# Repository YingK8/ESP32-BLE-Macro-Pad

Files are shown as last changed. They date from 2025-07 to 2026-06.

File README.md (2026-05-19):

# ESP32 BLE HID Macropad

A compact, programmable macropad with Bluetooth connectivity, featuring 6 mechanical keys and a rotary encoder for media control.





## Features

- 6-key mechanical switch matrix
- Rotary encoder for volume/scroll control
- Bluetooth HID (no drivers required)
- Supports both keyboard and media controls
- Customizable key mappings

## Hardware

| Component | Quantity |
|---|---|
| ESP32 Dev Board | 1 |
| Mechanical Keyswitches | 6 |
| Rotary Encoder | 1 |
| 1N4148 Diodes | 6 |

## Pinout

| Function | ESP32 Pin |
|---|---|
| Row 1 | GPIO 5 |
| Row 2 | GPIO 6 |
| Col 1 | GPIO 4 |
| Col 2 | GPIO 7 |
| Col 3 | GPIO 8 |
| Encoder A | GPIO 9 |
| Encoder B | GPIO 10 |

## Installation

1. Wire components according to pinout table
2. Install Arduino IDE with ESP32 support
3. Install required libraries:
   - ESP32 BLE Arduino
   - RotaryEncoder
4. Upload firmware to ESP32

## Usage

1. Power on the macropad
2. Pair with "ESP32 Macropad" via Bluetooth
3. Default layout:
   - Top row: Media controls
   - Bottom row: Programmable macros
   - Encoder: Volume control

## Customization

Edit the keymap in the source code:

```cpp
const uint8_t keys[ROWS][COLS] = {
  {MEDIA_PLAY, MEDIA_VOL_UP, MEDIA_VOL_DOWN},
  {KEY_F13, KEY_F14, KEY_F15}
};

## Pomodoro UI + Task Sync (macro-pad/)

- Display: ST7789 240x280 SPI. Set pins in `macro-pad/include/Config.h`.
- Controls: top-left key toggles pause/resume; encoder rotation moves selection; top-right key (encoder click in matrix) checks/unchecks a task.
- Task payload: newline-delimited titles terminated by `--END--`.

CLI helper (requires `pip install bleak`):

```bash
python3 macro-pad/tools/push_tasks.py "Write report" "Review PRs"
```

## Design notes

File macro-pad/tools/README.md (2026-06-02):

# Task Push Tools

Two Python scripts for sending a task list to the MacroPad over BLE. Both do the same job; `send_tasks.py` is simpler for quick CLI use, `push_tasks.py` has more flags (`--address`, `--timeout`).

## Requirements

```
pip install bleak
```

## Usage

```bash
# Inline tasks
python send_tasks.py "grasp map" "orca handoff" "teleop"

# From a file (one task per line)
python send_tasks.py --file tasks.txt

# push_tasks.py with optional flags
python push_tasks.py --name "ESP32 MacroPad" --timeout 8.0 "task one" "task two"
python push_tasks.py --address AA:BB:CC:DD:EE:FF --file tasks.txt
```

Tasks are automatically uppercased before sending — the display font only contains capital letters.

---

## How it works: end-to-end

### 1. BLE GATT — the transport layer

BLE (Bluetooth Low Energy) uses a client/server model called **GATT** (Generic Attribute Profile).

- The **ESP32 is the server**: it hosts a *Service* (a logical grouping) that contains a *Characteristic* (a named data slot). Think of a characteristic like a file you can read or write over the air.
- The **laptop is the client**: it connects, discovers the service, and writes bytes to the characteristic.

Services and characteristics are identified by **UUIDs** (128-bit IDs). Both tools and the firmware share the same pair:

```
Service UUID:        c3a7b7a0-3c1b-4d46-9f5c-9f0d9d1a9d01
Characteristic UUID: c3a7b7a0-3c1b-4d46-9f5c-9f0d9d1a9d02
```

### 2. MTU and chunking

BLE ATT (Attribute Protocol) has a default **MTU of 23 bytes**, leaving only **20 bytes of usable payload** per write (3 bytes are consumed by the ATT header). Without explicit MTU negotiation, any write larger than 20 bytes will be silently truncated or rejected.

The tools split the payload into 20-byte chunks and write them one at a time:

```python
for i in range(0, len(data), CHUNK_SIZE):
    await client.write_gatt_char(CHAR_UUID, data[i:i + CHUNK_SIZE], response=False)
```

`response=False` uses **Write Without Response** (BLE opcode 0x52), which is faster than a confirmed write but provides no acknowledgement. It is appropriate here because the terminator-detection scheme makes retries unnecessary.

### 3. The terminator protocol

Because the payload arrives as many small chunks, the ESP32 can't know when the transfer is complete from any single write. The protocol uses a sentinel string `--END--` to mark the end:

```
GRASP MAP\nORCA HANDOFF\nTELEOP\n--END--
│                                │
└─ newline-separated task names  └─ sentinel
```

The firmware accumulates chunks in a fixed buffer and scans for `--END--` after each write:

```cpp
// TaskSync.cpp — onWrite()
const char* term = strstr(_buf, "--END--");
if (term) {
    enqueue(_buf, term - _buf);  // copy everything before "--END--"
    _buf[0] = '\0';              // reset for next transfer
}
```

Everything before the sentinel is the complete payload; the sentinel itself is discarded.

### 4. Thread-safety with a spinlock

BLE callbacks run in a FreeRTOS task managed by the ESP32 BLE stack — a different task from the Arduino `loop()`. Sharing memory between them without protection causes **race conditions** (one task reads while the other writes, getting garbled data).

TaskSync uses a **spinlock** (`portMUX_TYPE`) to make the handoff atomic:

```cpp
// Writer side (BLE callback task):
portENTER_CRITICAL(&taskMux);
memcpy(pendingPayload, data, n);
payloadReady = true;
portEXIT_CRITICAL(&taskMux);

// Reader side (loop() task):
portENTER_CRITICAL(&taskMux);
strncpy(out, pendingPayload, maxLen - 1);
payloadReady = false;
portEXIT_CRITICAL(&taskMux);
```

`portENTER_CRITICAL` on a single-core ESP32-C3 disables interrupts for the critical section. `payloadReady` is marked `volatile` so the compiler doesn't cache its value in a register across the critical section boundary.

### 5. Parsing the payload

Once `loop()` picks up the payload via `getNextTaskPayload()`, `applyTasks()` parses it line by line:

```cpp
const char* nl = strchr(p, '\n');
size_t len = nl ? (size_t)(nl - p) : strlen(p);  // handles last line with no \n
```

Each task is uppercased (ASCII arithmetic: `*q -= 32` maps 'a'→'A'), stored in `tasks[][]`, and the display is flagged dirty for the next `loop()` iteration.

### 6. Display update

`buildScreen()` in `ui.cpp` rebuilds the entire screen as one flat string and hands it to LVGL's label renderer. Tasks appear as 12-character rows:

```
1 GRASP MAP  
2 ORCA HANDOF   ← truncated at 12 chars silently
3 TELEOP     <  ← selected row gets '<' cursor
```

---

## Full data flow

```
Python                ESP32 BLE stack          Arduino loop()        LVGL
──────                ───────────────          ──────────────        ────
tasks.upper()
→ payload string
→ split into 20B chunks
→ write_gatt_char() ×N
                      onWrite() ×N
                      accumulate in _buf
                      strstr("--END--") found
                      enqueue(payload)         getNextTaskPayload()
                                               applyTasks()
                                               tasksDirty = true
                                               updateTaskQueue()     buildScreen()
                                                                     lv_label_set_text()
                                                                     → pixels on display
```

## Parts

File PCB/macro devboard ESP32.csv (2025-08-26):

Reference | Qty | Value | DNP | Exclude from BOM | Exclude from Board | Footprint | Datasheet
C1,C6,C7 | 3 | 100nF |  |  |  | Capacitor_SMD:C_0603_1608Metric_Pad1.08x0.95mm_HandSolder | ~
C3,C4,C5,C8,C9 | 5 | 2.2uF |  |  |  | Capacitor_SMD:C_0603_1608Metric_Pad1.08x0.95mm_HandSolder | ~
D2,D3,D4,D5,D6,D7,D11 | 7 | 1N4148WT |  |  |  | Diode_SMD:D_SOD-323F | https://www.diodes.com/assets/Datasheets/ds30396.pdf
D8,D9,D10,D12 | 4 | LED |  |  |  | LED_SMD:LED_0805_2012Metric_Pad1.15x1.40mm_HandSolder | https://mm.digikey.com/Volume0/opasdata/d220001/medias/docus/1134/LTST-C171GKT.pdf,~
H1,H2 | 2 | MountingHole |  | Excluded from BOM |  | MountingHole:MountingHole_2.7mm_M2.5 | ~
J1 | 1 | 12402012E212A |  |  |  | 12402012E212A:AMPHENOL_12402012E212A
J2 | 1 | Conn_01x02_Pin |  |  |  | Connector_JST:JST_PH_B2B-PH-K_1x02_P2.00mm_Vertical | ~
J3 | 1 | Conn_02x04_Odd_Even |  |  |  | Connector_PinSocket_2.54mm:PinSocket_2x04_P2.54mm_Vertical | ~
JP10,JP11 | 2 | SolderJumper_2_Open |  | Excluded from BOM |  | Jumper:SolderJumper-2_P1.3mm_Open_RoundedPad1.0x1.5mm | ~
Q1 | 1 | BSS84LT1G |  |  |  | Package_TO_SOT_SMD:TSOT-23_HandSoldering | https://ngspice.sourceforge.io/docs/ngspice-html-manual/manual.xhtml#cha_MOSFETs
R1,R2 | 2 | 5.1k |  |  |  | Resistor_SMD:R_0603_1608Metric_Pad0.98x0.95mm_HandSolder | ~
R4,R5 | 2 | 22 |  |  |  | Resistor_SMD:R_0603_1608Metric_Pad0.98x0.95mm_HandSolder | ~
R6,R7,R11 | 3 | 100 |  |  |  | Resistor_SMD:R_0603_1608Metric_Pad0.98x0.95mm_HandSolder | ~
R10 | 1 | 100k |  |  |  | Resistor_SMD:R_0603_1608Metric_Pad0.98x0.95mm_HandSolder | ~
R12 | 1 | 10k |  |  |  | Resistor_SMD:R_0603_1608Metric_Pad0.98x0.95mm_HandSolder | ~
R13 | 1 | 2.2k |  |  |  | Resistor_SMD:R_0603_1608Metric_Pad0.98x0.95mm_HandSolder | ~
R14 | 1 | 2.7k |  |  |  | Resistor_SMD:R_0603_1608Metric_Pad0.98x0.95mm_HandSolder | ~
S1 | 1 | PEC12R-4225F-S0024 |  |  |  | PEC12R_4225F_S0024:XDCR_PEC12R-4225F-S0024
SW1,SW6,SW7,SW8,SW9 | 5 | MX_SW_HS |  |  |  | keyswitches:Kailh_socket_MX | ~
SW3 | 1 | RST |  |  |  | Button_Switch_SMD:SW_Tactile_SPST_NO_Straight_CK_PTS636Sx25SMTRLFS | ~
U1 | 1 | ESP32-C3-WROOM-02 |  |  |  | RF_Module:ESP32-C3-WROOM-02 | https://www.espressif.com/sites/default/files/documentation/esp32-c3-wroom-02_datasheet_en.pdf
U2 | 1 | MCP73831T-2ACI_OT |  |  |  | MCP73831T_2ACI_OT:SOT95P280X145-5N
U3 | 1 | USBLC6-2SC6 |  |  |  | Package_TO_SOT_SMD:SOT-23-6_Handsoldering | https://www.st.com/resource/en/datasheet/usblc6-2.pdf
U4 | 1 | XC6210B332MR |  |  |  | Package_TO_SOT_SMD:SOT-23-5 | https://www.torexsemi.com/file/xc6210/XC6210.pdf

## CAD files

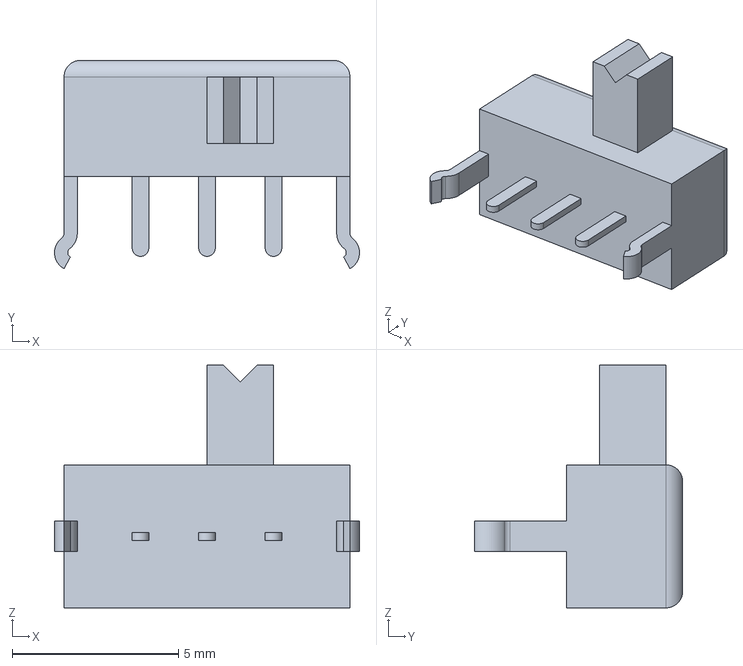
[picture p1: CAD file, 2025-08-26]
PCB/components/1825232_1/c-1825232-1-b-3d.stp
9.17 x 6.27 x 7.30 mm

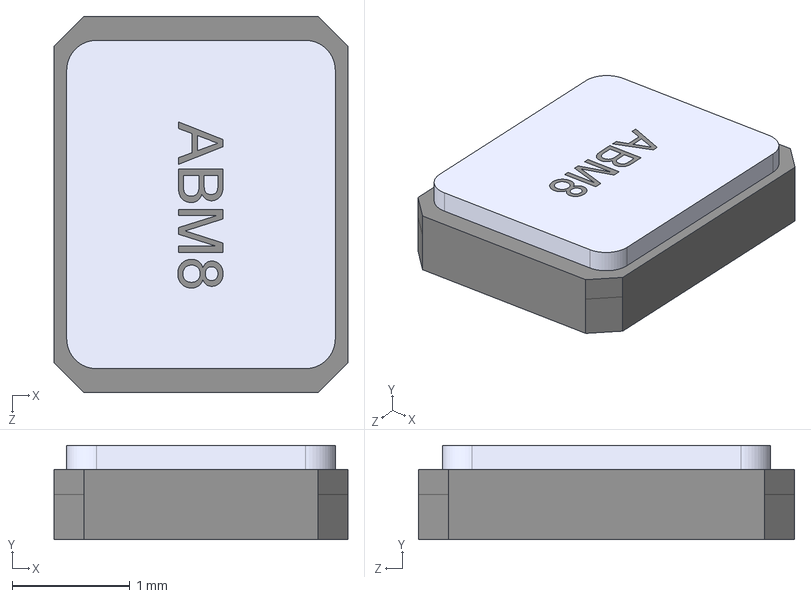
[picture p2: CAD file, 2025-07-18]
PCB/components/ABM8_16_000MHZ_D1X_T/ABM8-16.000MHz-D1X-T.step
2.50 x 0.8 x 3.20 mm

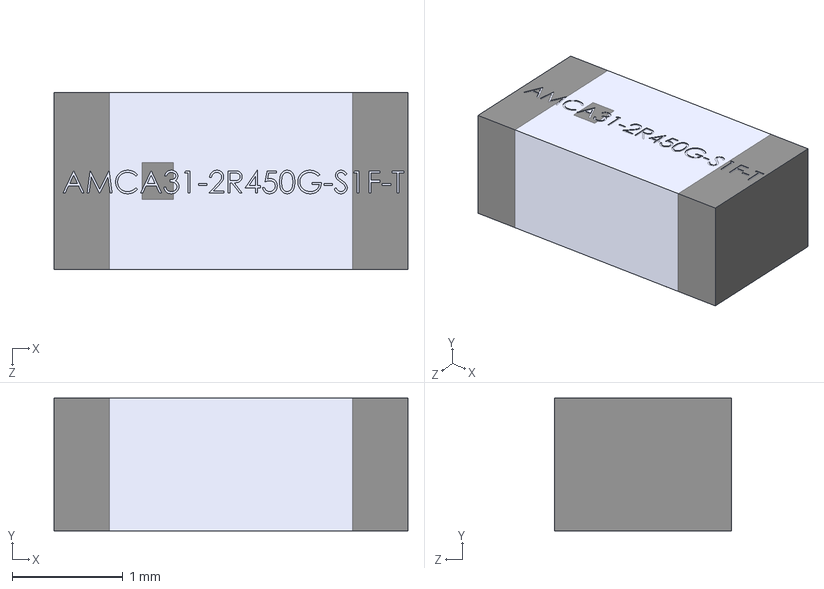
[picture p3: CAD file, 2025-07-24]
PCB/components/AMCA31_2R450G_S1F_T3/AMCA31-2R450G-S1F-T3.step
3.20 x 1.20 x 1.60 mm

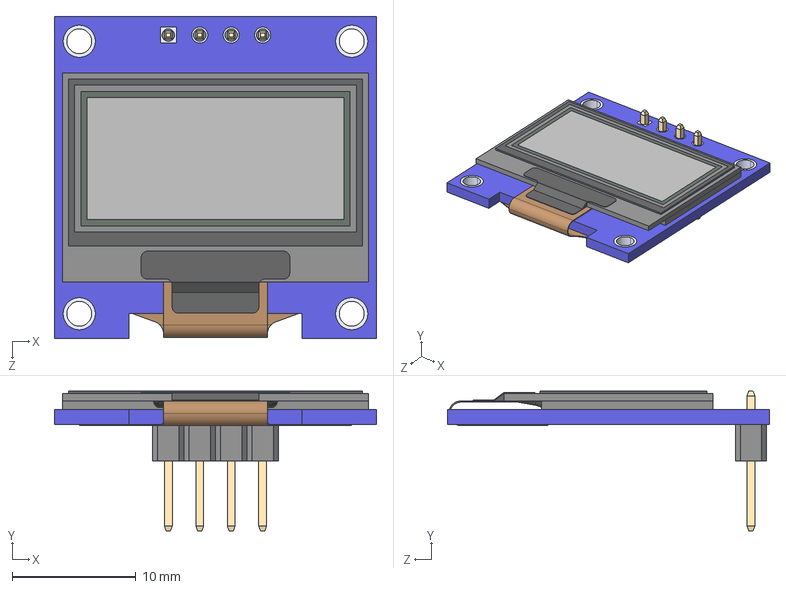
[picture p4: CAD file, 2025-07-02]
PCB/components/DM-OLED096-636/DM-OLED096-636.step
26.0 x 11.3 x 26.0 mm
DM-OLED096-636_Module
DM-OLED096-636_Panel

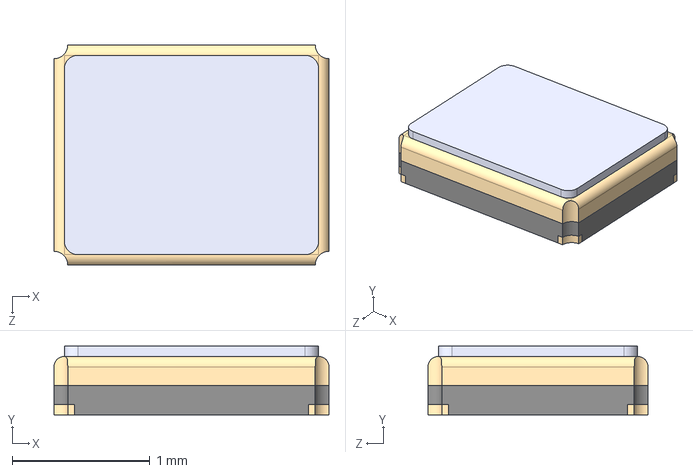
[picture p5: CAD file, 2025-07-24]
PCB/components/ECS_320_8_37B_CKY_TR/ECS-320-8-37B-CKY-TR.step
2.00 x 0.5 x 1.60 mm

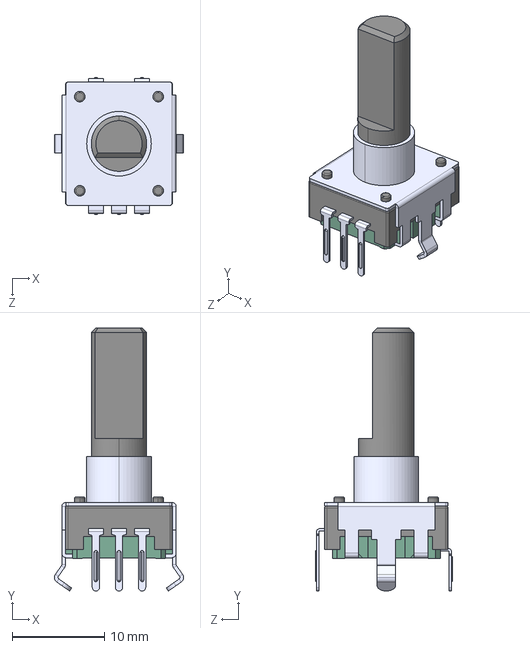
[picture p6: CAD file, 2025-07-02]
PCB/components/PEC12R_4225F_S0024/PEC12R-4225F-S0024.step
14.0 x 28.5 x 14.9 mm

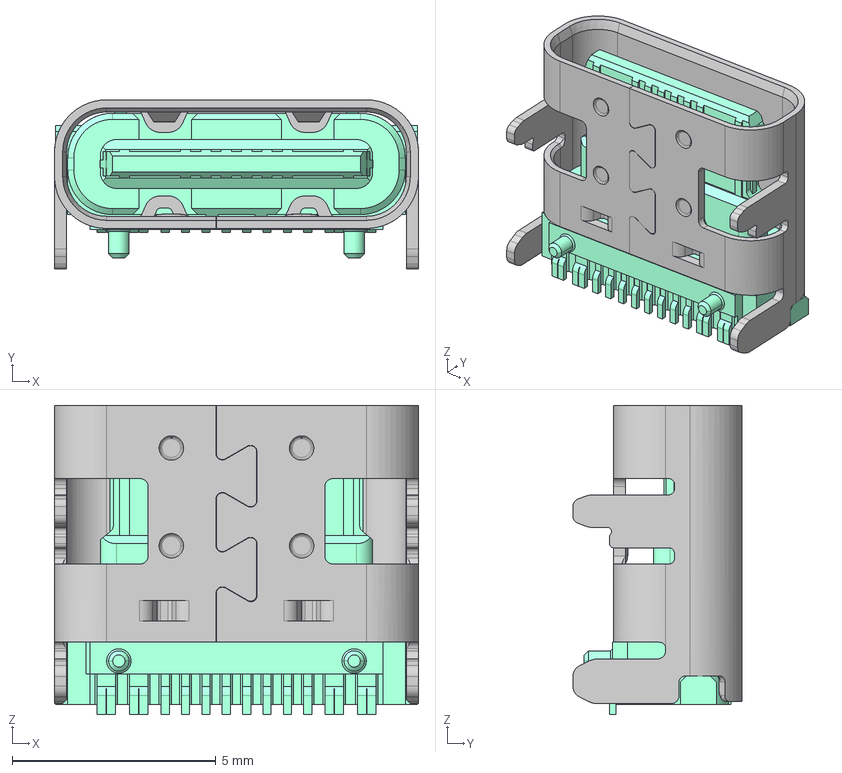
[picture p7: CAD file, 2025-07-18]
PCB/components/12402012E212A/12402012E212A.step
8.94 x 4.16 x 7.60 mm

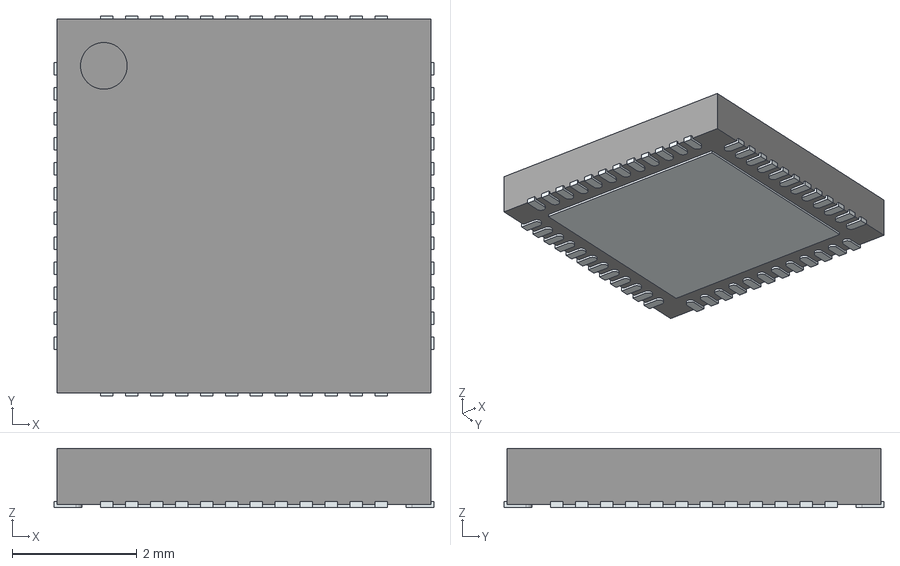
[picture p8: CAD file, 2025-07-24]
PCB/components/LIB_nRF52840-QFAA-F-R7/nRF52840-QFAA-F-R7/3D/nRF52840-QFAA-F-R7.stp
6.10 x 6.10 x 0.95 mm
ThermalPin
PinsArrayLR
PinsArrayTB

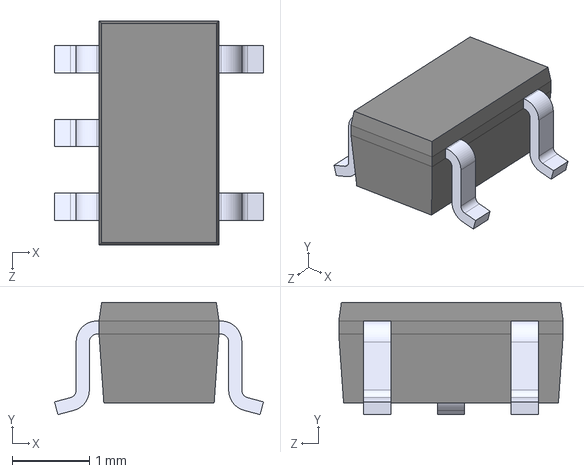
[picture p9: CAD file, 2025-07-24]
PCB/components/MCP73831T_2ACI_OT/MCP73831T-2ACI_OT.step
2.70 x 1.45 x 2.90 mm

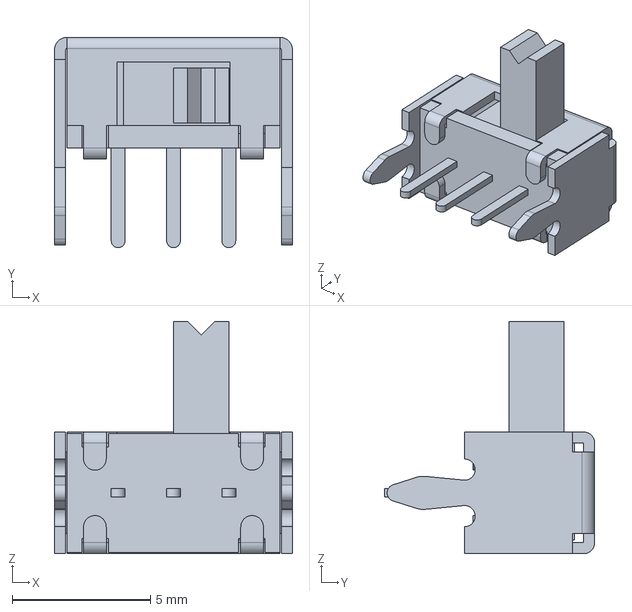
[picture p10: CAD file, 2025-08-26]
PCB/components/OS102011MA1QN1/OS102011MA1QN1.stp
8.60 x 7.60 x 8.40 mm

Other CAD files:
PCB/components/LIB_nRF52840-QFAA-F-R7/nRF52840-QFAA-F-R7/Allegro/qfn40p600x600x95-49n-d.psm
PCB/components/LIB_nRF52840-QFAA-F-R7/nRF52840-QFAA-F-R7/DEHDL/nrf52840_qfaa_f_r7/chips/chips.prt

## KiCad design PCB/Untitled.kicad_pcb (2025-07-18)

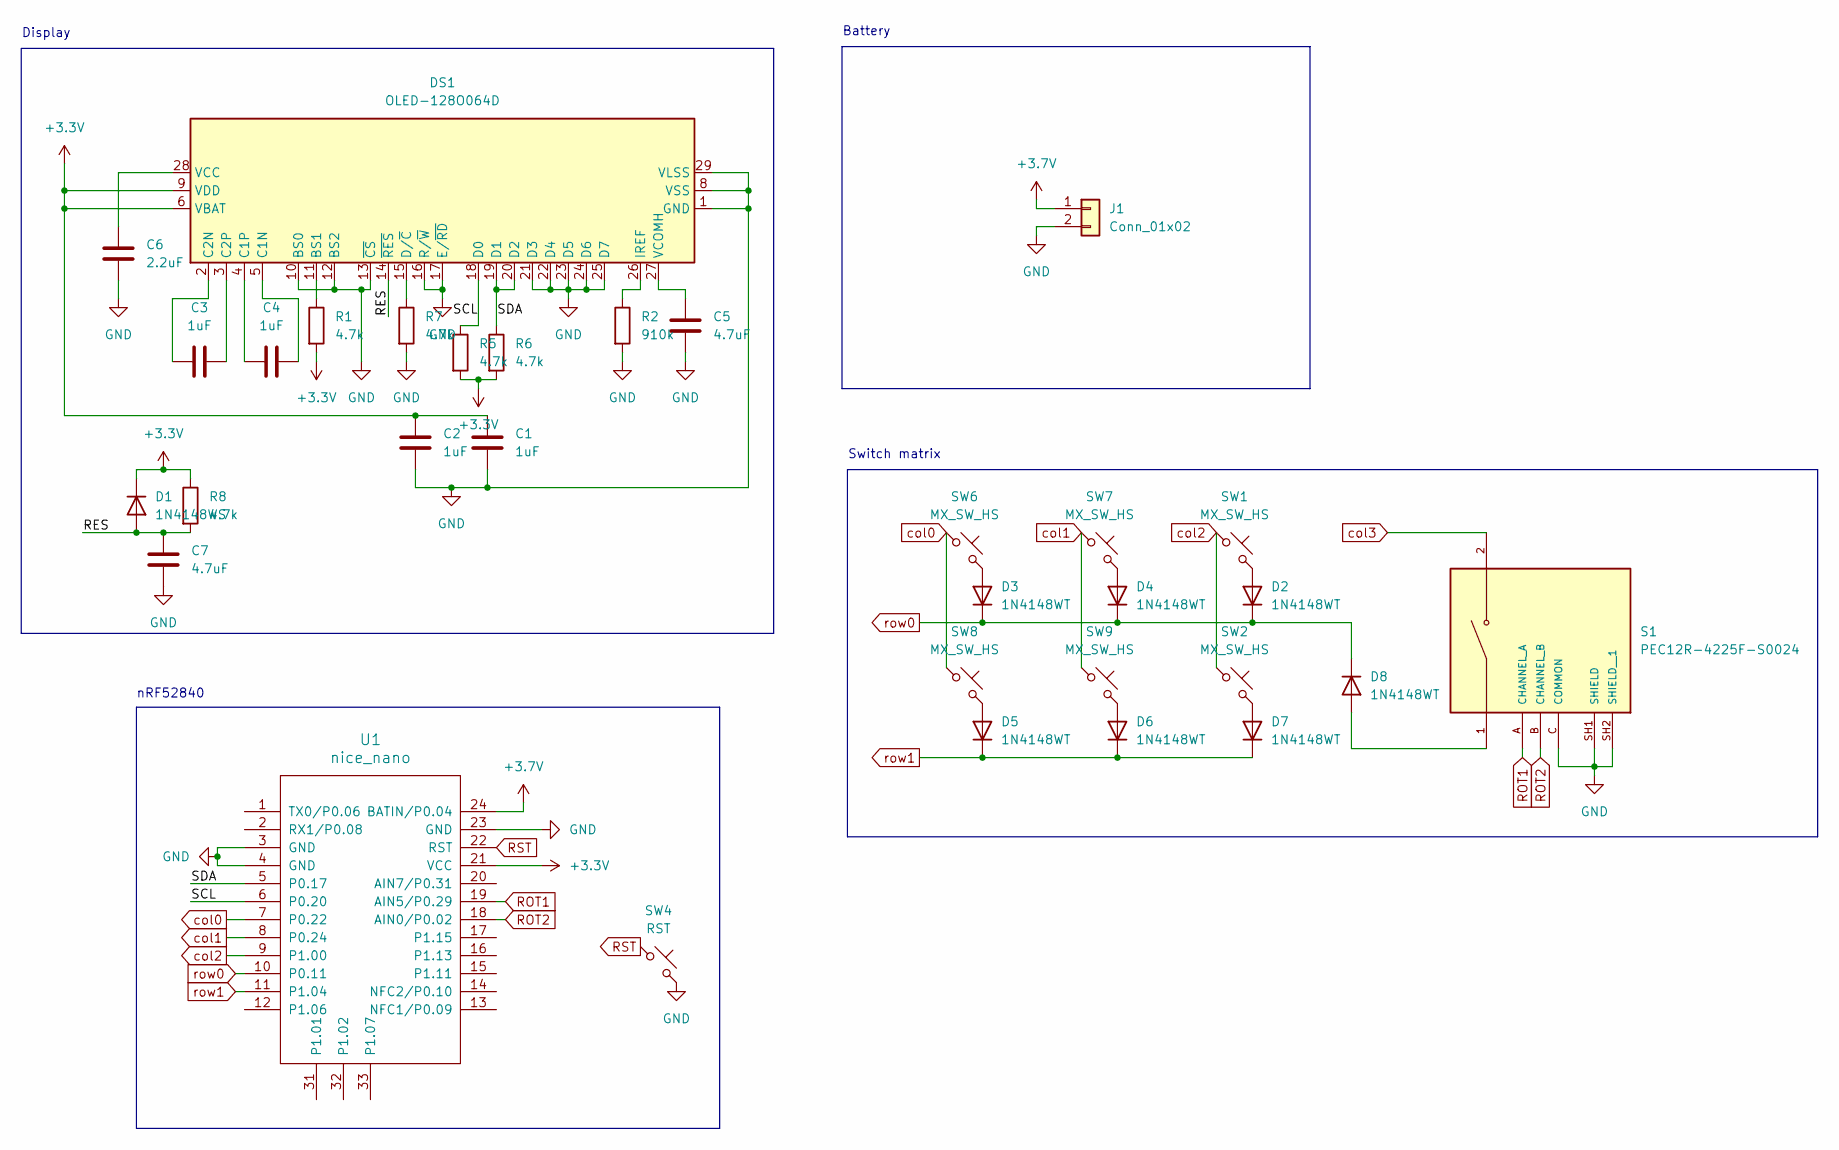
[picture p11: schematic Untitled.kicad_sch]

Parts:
C1, C2, C3, C4: 1uF; C_0805_2012Metric_Pad1.18x1.45mm_HandSolder
C5, C7: 4.7uF; C_0805_2012Metric_Pad1.18x1.45mm_HandSolder
C6: 2.2uF; C_0805_2012Metric_Pad1.18x1.45mm_HandSolder
D1: 1N4148WS; D_SOD-323F
D2, D3, D4, D5, D6, D7, D8: 1N4148WT; D_SOD-323F
DS1: OLED-128O064D
J1: Conn_01x02; JST_PH_S2B-PH-K_1x02_P2.00mm_Horizontal
R1, R5, R6, R7, R8: 4.7k; R_0805_2012Metric_Pad1.20x1.40mm_HandSolder
R2: 910k; R_0805_2012Metric_Pad1.20x1.40mm_HandSolder
S1: PEC12R-4225F-S0024; XDCR_PEC12R-4225F-S0024; PARTREV 07/21
SW1, SW2, SW6, SW7, SW8, SW9: MX_SW_HS; Kailh_socket_MX
SW4: RST; SW_Tactile_SPST_NO_Straight_CK_PTS636Sx25SMTRLFS
U1: nice_nano

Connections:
+3.3V: C1.2, C2.2, D1.1 (K), DS1.6 (VBAT), DS1.9 (VDD), R1.2, R5.2, R6.2, R8.1, U1.21 (VCC)
+3.7V: J1.1, U1.24 (BATIN/P0.04)
/RES: C7.2, D1.2 (A), DS1.14 (~RES), R8.2
/SCL: DS1.18 (D0), R5.1, U1.6 (P0.20)
/SDA: DS1.19 (D1), DS1.20 (D2), R6.1, U1.5 (P0.17)
GND: C1.1, C2.1, C5.1, C6.1, C7.1, DS1.1 (GND), DS1.8 (VSS), DS1.10 (BS0), DS1.12 (BS2), DS1.13 (~CS), DS1.16 (R/~W), DS1.17 (E/~RD), DS1.21 (D3), DS1.22 (D4), DS1.23 (D5), DS1.24 (D6), DS1.25 (D7), DS1.29 (VLSS), DS1.30 (GND), J1.2, R2.2, R7.2, S1.C (COMMON), S1.SH1 (SHIELD), S1.SH2 (SHIELD__1), SW4.2, U1.3 (GND), U1.4 (GND), U1.23 (GND)
unnamed: D2.2 (A), SW1.2
unnamed: D3.2 (A), SW6.2
unnamed: D4.2 (A), SW7.2
unnamed: D5.2 (A), SW8.2
unnamed: D6.2 (A), SW9.2
unnamed: D7.2 (A), SW2.2
unnamed: D8.2 (A), S1.1
unnamed: DS1.11 (BS1), R1.1
unnamed: C4.2, DS1.5 (C1N)
unnamed: C4.1, DS1.4 (C1P)
unnamed: C3.1, DS1.2 (C2N)
unnamed: C3.2, DS1.3 (C2P)
unnamed: DS1.15 (D/~C), R7.1
unnamed: DS1.26 (IREF), R2.1
unnamed: C6.2, DS1.28 (VCC)
unnamed: C5.2, DS1.27 (VCOMH)
ROT1: S1.A (CHANNEL_A), U1.19 (AIN5/P0.29)
ROT2: S1.B (CHANNEL_B), U1.18 (AIN0/P0.02)
RST: SW4.1, U1.22 (RST)
col0: SW6.1, SW8.1, U1.7 (P0.22)
col1: SW7.1, SW9.1, U1.8 (P0.24)
col2: SW1.1, SW2.1, U1.9 (P1.00)
col3: S1.2
row0: D2.1 (K), D3.1 (K), D4.1 (K), D8.1 (K), U1.10 (P0.11)
row1: D5.1 (K), D6.1 (K), D7.1 (K), U1.11 (P1.04)

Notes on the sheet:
Battery
Display
Switch matrix
nRF52840

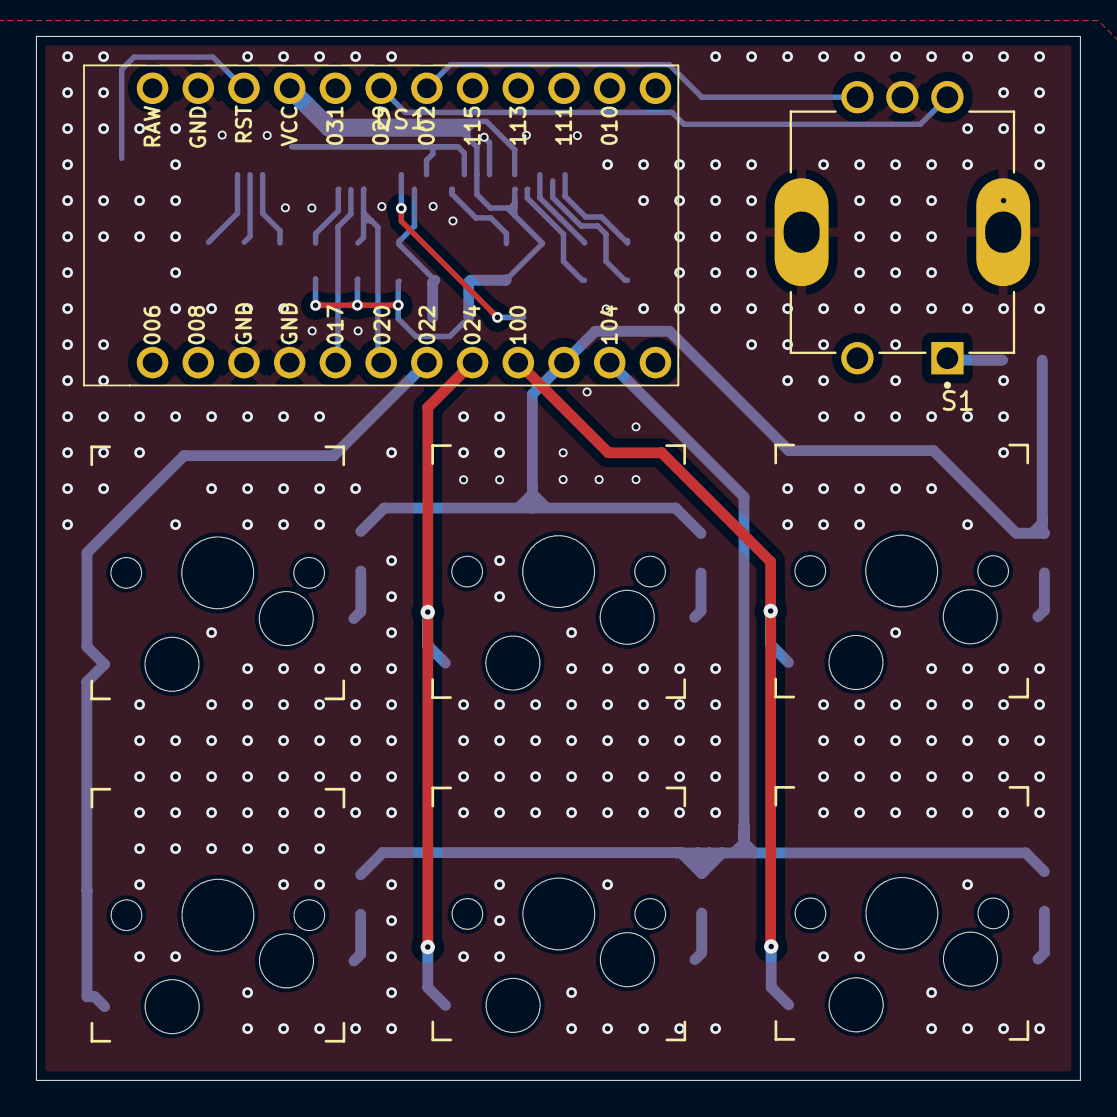
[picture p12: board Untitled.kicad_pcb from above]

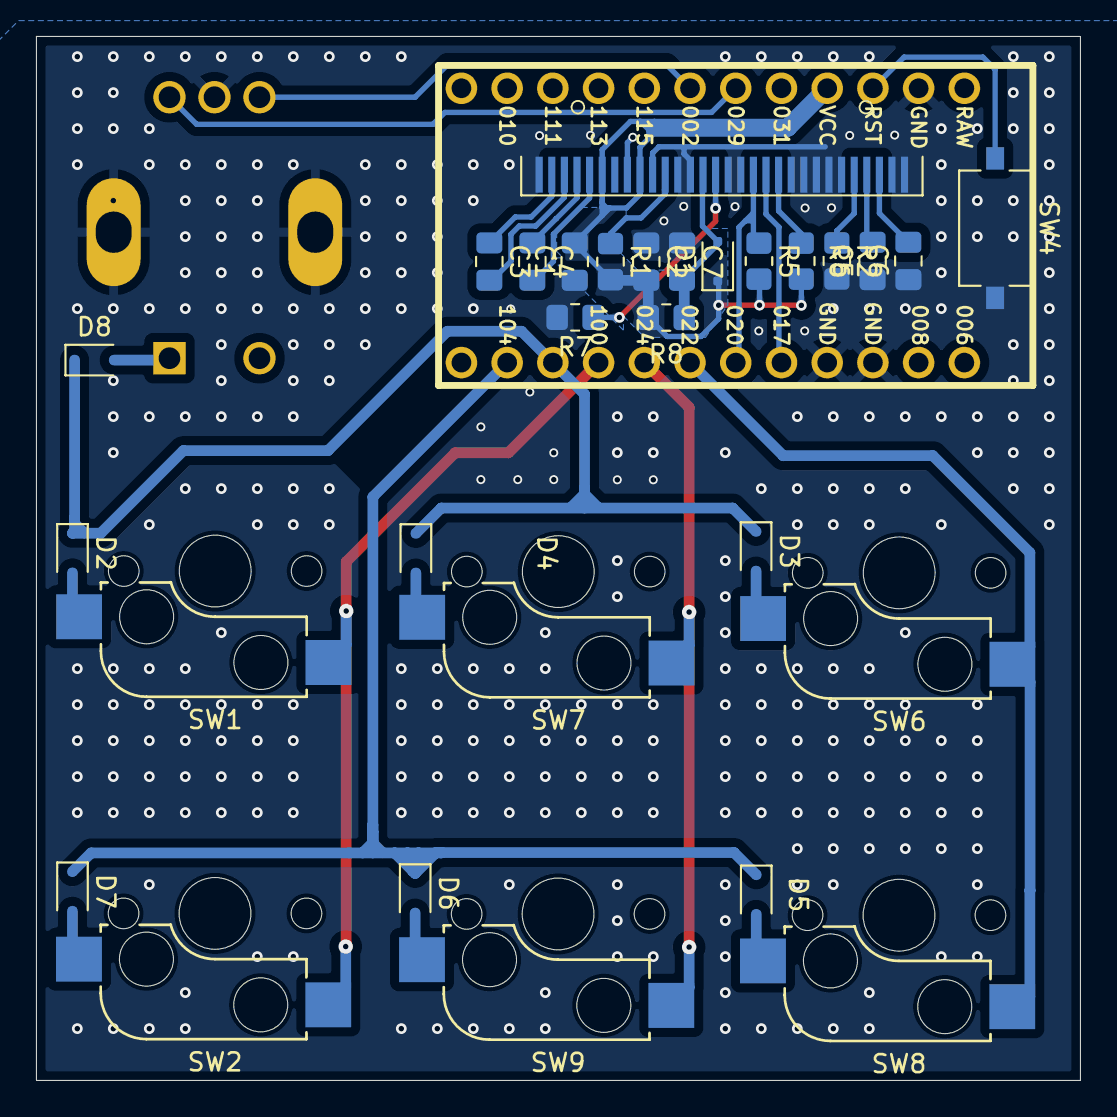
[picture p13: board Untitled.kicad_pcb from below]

Board: 2 copper layers, 58.0 x 58.0 mm, 31 parts (23 on the bottom side), 29 nets.

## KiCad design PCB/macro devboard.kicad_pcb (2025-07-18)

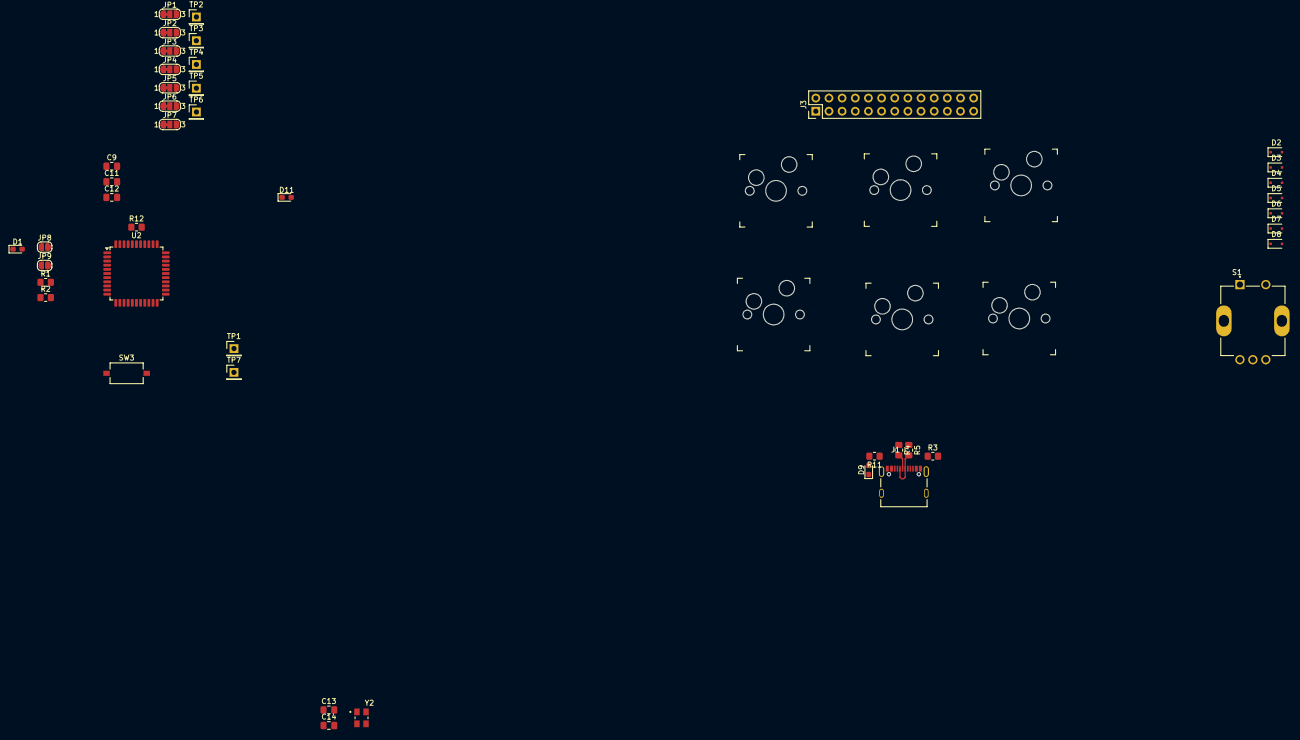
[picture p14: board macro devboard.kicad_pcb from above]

Board: 2 copper layers, 50 parts (0 on the bottom side), 58 nets.

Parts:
C9, C11, C12: 1uF; C_0805_2012Metric_Pad1.18x1.45mm_HandSolder
C13, C14: 18pF; C_0805_2012Metric_Pad1.18x1.45mm_HandSolder
D1, D9, D11: LED; LED_0603_1608Metric_Pad1.05x0.95mm_HandSolder
D2, D3, D4, D5, D6, D7, D8: 1N4148WT; D_SOD-323F
J1: 12402012E212A; AMPHENOL_12402012E212A
J3: Conn_02x13_Counter_Clockwise; PinHeader_2x13_P2.54mm_Vertical
JP1, JP2, JP3, JP4, JP5, JP6, JP7: SolderJumper_3_Bridged12; SolderJumper-3_P1.3mm_Bridged12_RoundedPad1.0x1.5mm_NumberL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
JP8, JP9: SolderJumper_2_Open; SolderJumper-2_P1.3mm_Open_RoundedPad1.0x1.5mm
R1, R2, R11: 100; R_0805_2012Metric_Pad1.20x1.40mm_HandSolder
R3: 4.7k; R_0805_2012Metric_Pad1.20x1.40mm_HandSolder
R4, R5: 22; R_0805_2012Metric_Pad1.20x1.40mm_HandSolder
R12: 10k; R_0805_2012Metric_Pad1.20x1.40mm_HandSolder
S1: PEC12R-4225F-S0024; XDCR_PEC12R-4225F-S0024
SW1, SW2, SW6, SW7, SW8, SW9: MX_SW_HS; Kailh_socket_MX
SW3: RST; SW_Tactile_SPST_NO_Straight_CK_PTS636Sx25SMTRLFS
TP1, TP2, TP3, TP4, TP5, TP6, TP7: TestPoint; PinHeader_1x01_P2.54mm_Vertical
U2: ATmega32U4-A; TQFP-44_10x10mm_P0.8mm
Y2: ABM8-16.000MHz-D1X-T; XTAL_ABM8-16.000MHz-D1X-T

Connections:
+5V: J1.A4_B9 (VBUS), J3.1, J3.25, J3.26, R11.1, R12.2, U2.14 (VCC), U2.24 (AVCC), U2.34 (VCC), U2.44 (AVCC)
/CC1: J1.A5 (CC1_A), J1.B5 (CC1_B), R3.1
/Din+: J1.A6 (D+_A), J1.B6 (D+_B), R4.2
/Din-: J1.A7 (D-_A), J1.B7 (D-_B), R5.2
/RESET: R12.1, SW3.1, U2.13 (~RESET)
/UVCC: C11.1, U2.2 (UVCC), U2.7 (VBUS)
/XTAL1: C13.1, U2.17 (XTAL1), Y2.1
/XTAL2: C14.1, U2.16 (XTAL2), Y2.3
D+: R4.1, U2.4 (D+)
D-: R5.1, U2.3 (D-)
GND: C9.1, C11.2, C12.2, C13.2, C14.2, D1.1 (K), D9.1 (K), D11.1 (K), J1.A1_B12 (GND), J1.A8 (SBU1), J1.B1_A12 (GND__1), J1.B8 (SBU2), J1.SH1 (SHIELD), J1.SH2 (SHIELD__1), J1.SH3 (SHIELD__2), J1.SH4 (SHIELD__3), J3.7, J3.13, J3.16, J3.19, R3.2, S1.C (COMMON), S1.SH1 (SHIELD), S1.SH2 (SHIELD__1), SW3.2, U2.5 (UGND), U2.15 (GND), U2.23 (GND), U2.33 (~HWB/PE2), U2.35 (GND), U2.43 (GND), Y2.2 (GND), Y2.4 (GND__1)
unnamed: D1.2 (A), R1.1
unnamed: D2.2 (A), SW1.2
unnamed: D3.2 (A), SW6.2
unnamed: D4.2 (A), SW7.2
unnamed: D5.2 (A), SW8.2
unnamed: D6.2 (A), SW9.2
unnamed: D7.2 (A), SW2.2
unnamed: D8.2 (A), S1.1
unnamed: D9.2 (A), R11.2
unnamed: D11.2 (A), R2.1
unnamed: JP1.1 (A), TP5.1, U2.29 (PB5)
unnamed: JP2.1 (A), TP6.1, U2.30 (PB6)
unnamed: JP3.1 (A), TP4.1, U2.28 (PB4)
unnamed: JP4.1 (A), TP2.1, U2.31 (PC6)
unnamed: JP5.1 (A), TP3.1, U2.32 (PC7)
unnamed: JP6.1 (A), TP1.1, U2.26 (PD6)
unnamed: JP7.1 (A), TP7.1, U2.27 (PD7)
unnamed: JP8.1 (A), R1.2
unnamed: JP9.1 (A), R2.2
unnamed: JP9.2 (B), U2.25 (PD4)
unnamed: C12.1, U2.42 (AREF)
unnamed: C9.2, U2.6 (UCAP)
PB0/SS: J3.24, U2.8 (PB0)
PB1/SCK: J3.23, U2.9 (PB1)
PB2/MOSI: J3.22, U2.10 (PB2)
PB3/MISO: J3.21, U2.11 (PB3)
PB7/RTS: J3.20, U2.12 (PB7)
PC6: J3.15, JP4.3 (B)
PC7: J3.14, JP5.3 (B)
PD0/SCL: J3.12, U2.18 (PD0)
PD1/SDA: J3.11, U2.19 (PD1)
PD2/RXD1: J3.10, U2.20 (PD2)
PD3/TXD1: J3.9, U2.21 (PD3)
PD5/CTS: J3.8, U2.22 (PD5)
PF0: J3.6, U2.41 (PF0)
PF1: J3.5, U2.40 (PF1)
PF4: J3.4, U2.39 (PF4)
PF5: J3.3, U2.38 (PF5)
PF6: J3.2, U2.37 (PF6)
PF7/LED1: J3.17, JP8.2 (B), U2.36 (PF7)
ROT1: JP6.2 (C), S1.A (CHANNEL_A)
ROT2: JP7.2 (C), S1.B (CHANNEL_B)
col0: JP3.2 (C), SW6.1, SW8.1
col1: JP1.2 (C), SW7.1, SW9.1
col2: JP2.2 (C), SW1.1, SW2.1
row0: D2.1 (K), D3.1 (K), D4.1 (K), D8.1 (K), JP4.2 (C)
row1: D5.1 (K), D6.1 (K), D7.1 (K), JP5.2 (C)

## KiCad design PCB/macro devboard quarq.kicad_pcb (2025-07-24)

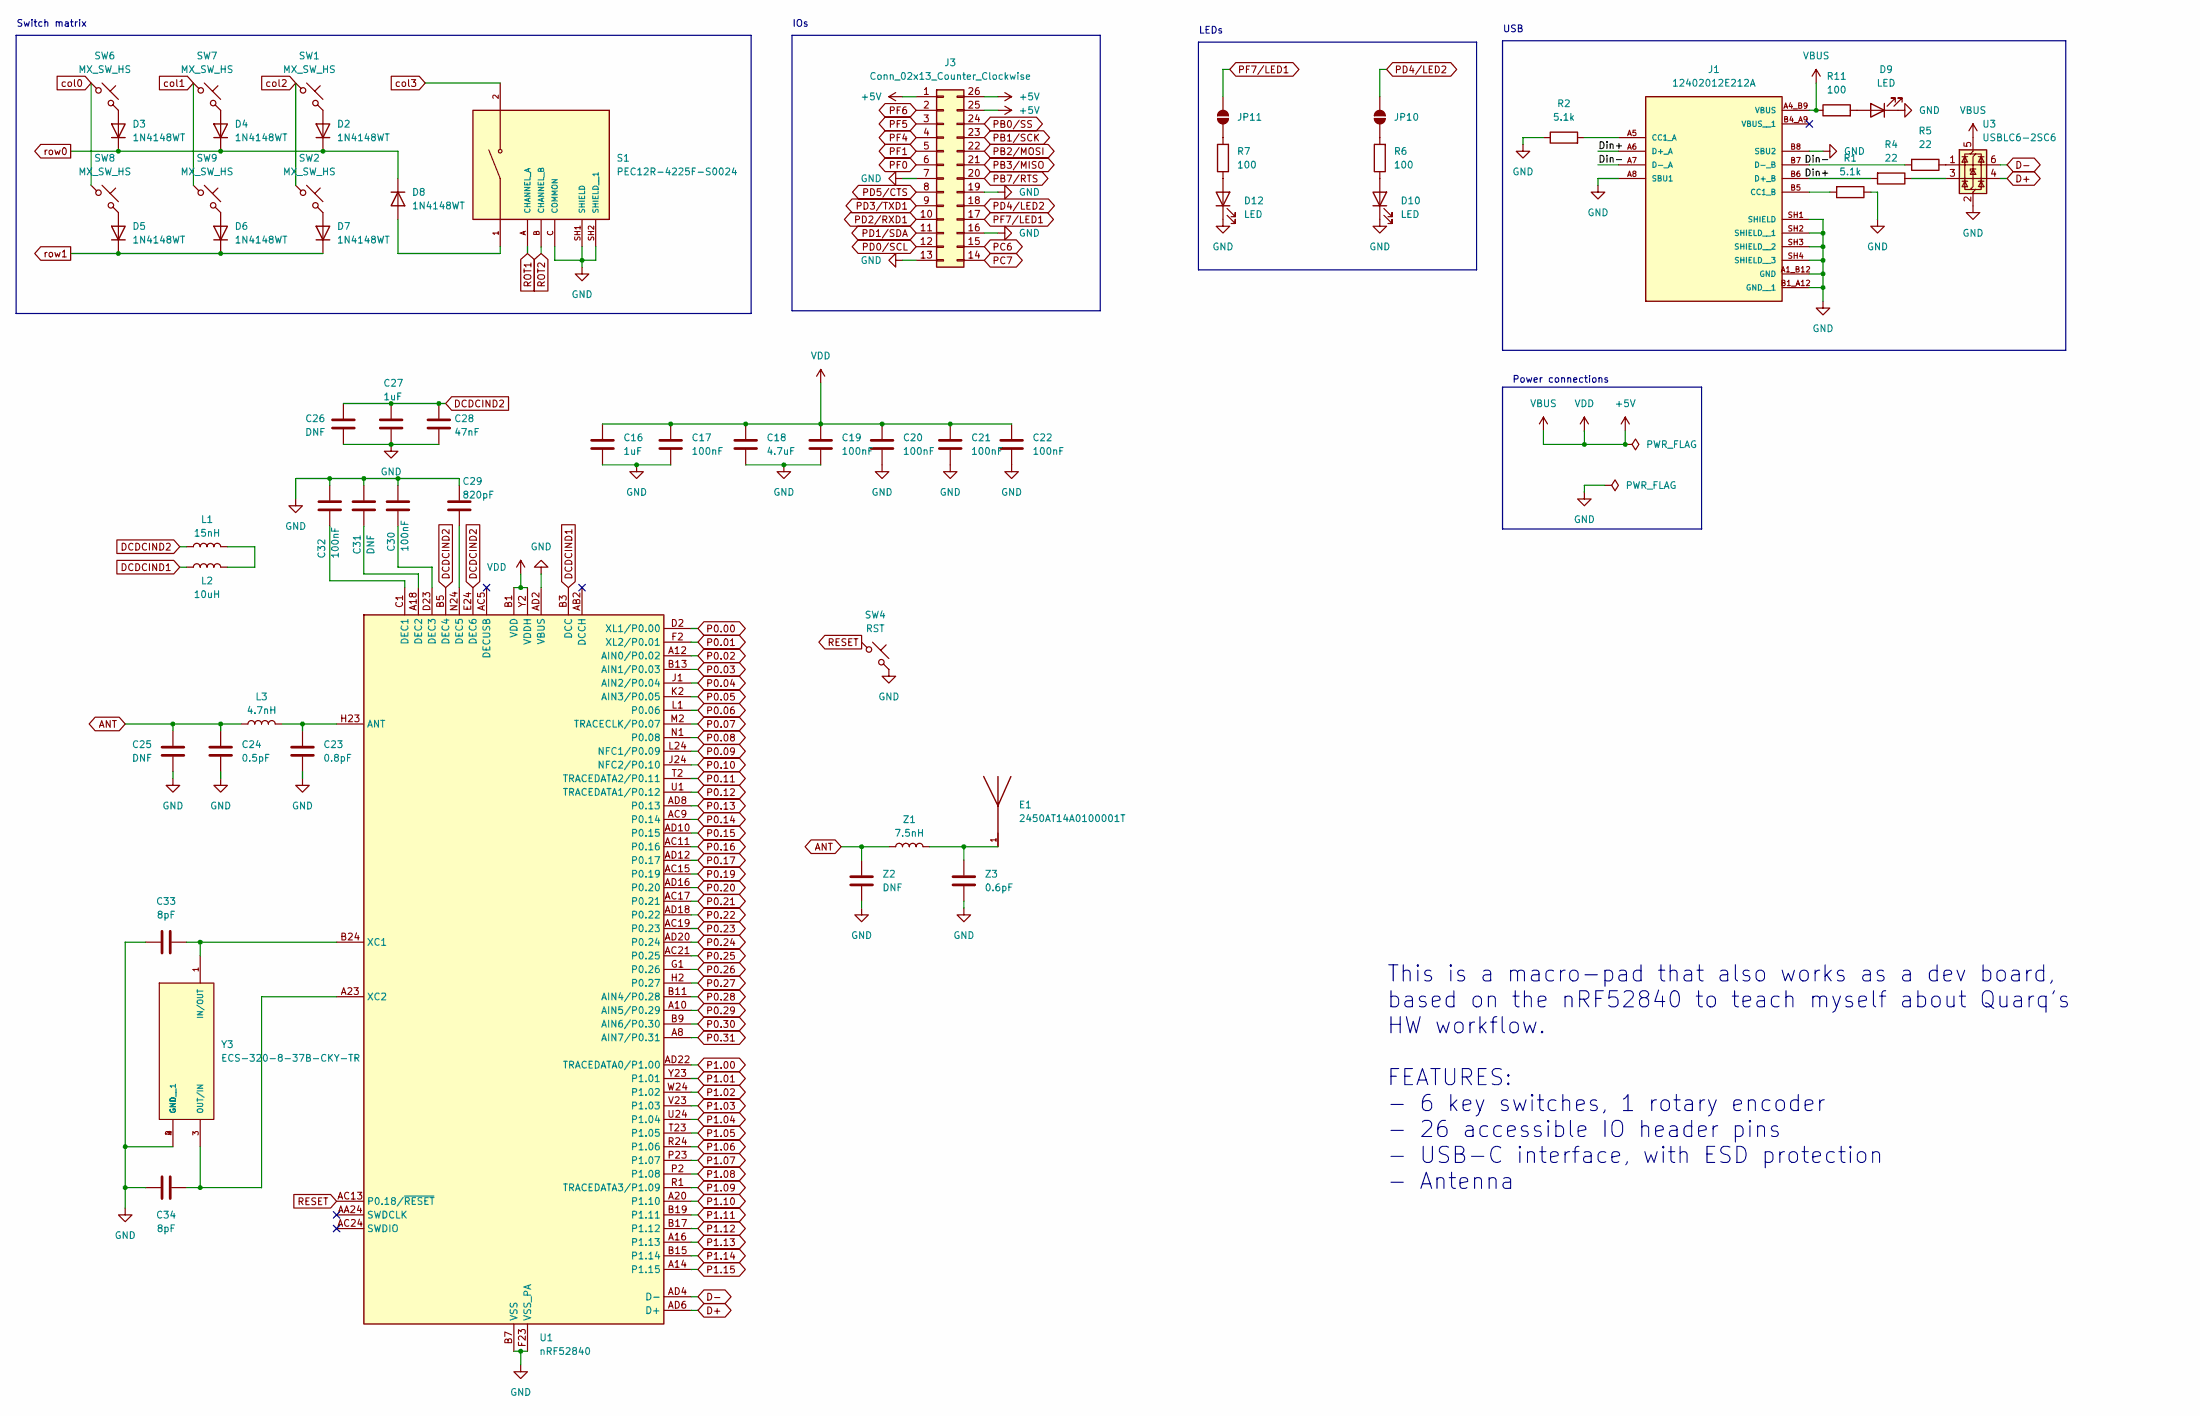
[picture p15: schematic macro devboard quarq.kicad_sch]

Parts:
C16, C27: 1uF; C_0201_0603Metric_Pad0.64x0.40mm_HandSolder
C17, C19, C20, C21, C22, C30, C32: 100nF; C_0201_0603Metric_Pad0.64x0.40mm_HandSolder
C18: 4.7uF; C_0805_2012Metric_Pad1.18x1.45mm_HandSolder
C23: 0.8pF; C_0201_0603Metric_Pad0.64x0.40mm_HandSolder
C24: 0.5pF; C_0201_0603Metric_Pad0.64x0.40mm_HandSolder
C25, C26, C31: DNF; C_0201_0603Metric_Pad0.64x0.40mm_HandSolder
C28: 47nF; C_0201_0603Metric_Pad0.64x0.40mm_HandSolder
C29: 820pF; C_0201_0603Metric_Pad0.64x0.40mm_HandSolder
C33, C34: 8pF; C_0201_0603Metric_Pad0.64x0.40mm_HandSolder
D2, D3, D4, D5, D6, D7, D8: 1N4148WT; D_SOD-323F
D9, D10, D12: LED; LED_0603_1608Metric_Pad1.05x0.95mm_HandSolder
E1: 2450AT14A0100001T; XDCR_AMCA31-2R450G-S1F-T3; PARTREV 03-21-19
J1: 12402012E212A; AMPHENOL_12402012E212A; PARTREV 4
J3: Conn_02x13_Counter_Clockwise; PinHeader_2x13_P2.54mm_Vertical
JP10, JP11: SolderJumper_2_Open; SolderJumper-2_P1.3mm_Open_RoundedPad1.0x1.5mm
L1: 15nH; L_0603_1608Metric_Pad1.05x0.95mm_HandSolder
L2: 10uH; L_0603_1608Metric_Pad1.05x0.95mm_HandSolder
L3: 4.7nH; L_0201_0603Metric_Pad0.64x0.40mm_HandSolder
R1, R2: 5.1k; R_0805_2012Metric_Pad1.20x1.40mm_HandSolder
R4, R5: 22; R_0805_2012Metric_Pad1.20x1.40mm_HandSolder
R6, R7, R11: 100; R_0805_2012Metric_Pad1.20x1.40mm_HandSolder
S1: PEC12R-4225F-S0024; XDCR_PEC12R-4225F-S0024; PARTREV 07/21
SW1, SW2, SW6, SW7, SW8, SW9: MX_SW_HS; Kailh_socket_MX
SW4: RST; SW_Tactile_SPST_NO_Straight_CK_PTS636Sx25SMTRLFS
U1: nRF52840; Nordic_AQFN-73-1EP_7x7mm_P0.5mm
U3: USBLC6-2SC6; SOT-23-6_Handsoldering
Y3: ECS-320-8-37B-CKY-TR; XTAL_ECS-160-9-37-CKM-TR; PARTREV 2017
Z1: 7.5nH; L_0402_1005Metric_Pad0.77x0.64mm_HandSolder
Z2: DNF; C_0402_1005Metric_Pad0.74x0.62mm_HandSolder
Z3: 0.6pF; C_0402_1005Metric_Pad0.74x0.62mm_HandSolder

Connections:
+5V: C16.1, C17.1, C18.1, C19.1, C20.1, C21.1, C22.1, J1.A4_B9 (VBUS), J3.1, J3.25, J3.26, R11.1, U1.A22 (VDD), U1.AD14 (VDD), U1.AD23 (VDD), U1.B1 (VDD), U1.W1 (VDD), U1.Y2 (VDDH), U3.5 (VBUS)
/Din+: J1.A6 (D+_A), J1.B6 (D+_B), R4.2
/Din-: J1.A7 (D-_A), J1.B7 (D-_B), R5.2
ANT: C24.1, C25.1, L3.1, Z1.1, Z2.1
D+: U1.AD6 (D+), U3.4 (I/O2)
D-: U1.AD4 (D-), U3.6 (I/O1)
DCDCIND1: L2.1, U1.B3 (DCC)
DCDCIND2: C26.1, C27.1, C28.1, L1.1, U1.B5 (DEC4), U1.E24 (DEC6)
GND: C16.2, C17.2, C18.2, C19.2, C20.2, C21.2, C22.2, C23.2, C24.2, C25.2, C26.2, C27.2, C28.2, C29.1, C30.1, C31.1, C32.1, C33.2, C34.2, D9.1 (K), D10.1 (K), D12.1 (K), J1.A1_B12 (GND), J1.A8 (SBU1), J1.B1_A12 (GND__1), J1.B8 (SBU2), J1.SH1 (SHIELD), J1.SH2 (SHIELD__1), J1.SH3 (SHIELD__2), J1.SH4 (SHIELD__3), J3.7, J3.13, J3.16, J3.19, R1.1, R2.1, S1.C (COMMON), S1.SH1 (SHIELD), S1.SH2 (SHIELD__1), SW4.2, U1.AD2 (VBUS), U1.B7 (VSS), U1.EP (VSS), U1.F23 (VSS_PA), U3.2 (GND), Y3.2 (GND), Y3.4 (GND__1), Z2.2, Z3.2
unnamed: D2.2 (A), SW1.2
unnamed: D3.2 (A), SW6.2
unnamed: D4.2 (A), SW7.2
unnamed: D5.2 (A), SW8.2
unnamed: D6.2 (A), SW9.2
unnamed: D7.2 (A), SW2.2
unnamed: D8.2 (A), S1.1
unnamed: D9.2 (A), R11.2
unnamed: D10.2 (A), R6.1
unnamed: D12.2 (A), R7.1
unnamed: E1.1, Z1.2, Z3.1
unnamed: J1.A5 (CC1_A), R2.2
unnamed: J1.B5 (CC1_B), R1.2
unnamed: JP10.1 (A), R6.2
unnamed: JP11.1 (A), R7.2
unnamed: L1.2, L2.2
unnamed: R4.1, U3.3 (I/O2)
unnamed: R5.1, U3.1 (I/O1)
unnamed: C23.1, L3.2, U1.H23 (ANT)
unnamed: C32.2, U1.C1 (DEC1)
unnamed: C31.2, U1.A18 (DEC2)
unnamed: C30.2, U1.D23 (DEC3)
unnamed: C29.2, U1.N24 (DEC5)
unnamed: C33.1, U1.B24 (XC1), Y3.1 (IN/OUT)
unnamed: C34.1, U1.A23 (XC2), Y3.3 (OUT/IN)
P0.00: U1.D2 (XL1/P0.00)
P0.01: U1.F2 (XL2/P0.01)
P0.02: U1.A12 (AIN0/P0.02)
P0.03: U1.B13 (AIN1/P0.03)
P0.04: U1.J1 (AIN2/P0.04)
P0.05: U1.K2 (AIN3/P0.05)
P0.06: U1.L1 (P0.06)
P0.07: U1.M2 (TRACECLK/P0.07)
P0.08: U1.N1 (P0.08)
P0.09: U1.L24 (NFC1/P0.09)
P0.10: U1.J24 (NFC2/P0.10)
P0.11: U1.T2 (TRACEDATA2/P0.11)
P0.12: U1.U1 (TRACEDATA1/P0.12)
P0.13: U1.AD8 (P0.13)
P0.14: U1.AC9 (P0.14)
P0.15: U1.AD10 (P0.15)
P0.16: U1.AC11 (P0.16)
P0.17: U1.AD12 (P0.17)
P0.19: U1.AC15 (P0.19)
P0.20: U1.AD16 (P0.20)
P0.21: U1.AC17 (P0.21)
P0.22: U1.AD18 (P0.22)
P0.23: U1.AC19 (P0.23)
P0.24: U1.AD20 (P0.24)
P0.25: U1.AC21 (P0.25)
P0.26: U1.G1 (P0.26)
P0.27: U1.H2 (P0.27)
P0.28: U1.B11 (AIN4/P0.28)
P0.29: U1.A10 (AIN5/P0.29)
P0.30: U1.B9 (AIN6/P0.30)
P0.31: U1.A8 (AIN7/P0.31)
P1.00: U1.AD22 (TRACEDATA0/P1.00)
P1.01: U1.Y23 (P1.01)
P1.02: U1.W24 (P1.02)
P1.03: U1.V23 (P1.03)
P1.04: U1.U24 (P1.04)
P1.05: U1.T23 (P1.05)
P1.06: U1.R24 (P1.06)
P1.07: U1.P23 (P1.07)
P1.08: U1.P2 (P1.08)
P1.09: U1.R1 (TRACEDATA3/P1.09)
P1.10: U1.A20 (P1.10)
P1.11: U1.B19 (P1.11)
P1.12: U1.B17 (P1.12)
P1.13: U1.A16 (P1.13)
P1.14: U1.B15 (P1.14)
P1.15: U1.A14 (P1.15)
PB0/SS: J3.24
PB1/SCK: J3.23
PB2/MOSI: J3.22
PB3/MISO: J3.21
PB7/RTS: J3.20
PC6: J3.15
PC7: J3.14
PD0/SCL: J3.12
PD1/SDA: J3.11
PD2/RXD1: J3.10
PD3/TXD1: J3.9
PD4/LED2: J3.18, JP10.2 (B)
PD5/CTS: J3.8
PF0: J3.6
PF1: J3.5
PF4: J3.4
PF5: J3.3
PF6: J3.2
PF7/LED1: J3.17, JP11.2 (B)
RESET: SW4.1, U1.AC13 (P0.18/~RESET)
ROT1: S1.A (CHANNEL_A)
ROT2: S1.B (CHANNEL_B)
col0: SW6.1, SW8.1
col1: SW7.1, SW9.1
col2: SW1.1, SW2.1
col3: S1.2
row0: D2.1 (K), D3.1 (K), D4.1 (K), D8.1 (K)
row1: D5.1 (K), D6.1 (K), D7.1 (K)

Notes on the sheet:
LEDs
Power connections
This is a macro-pad that also works as a dev board, based on the nRF52840 to teach myself about Quarq's HW workflow. FEATURES: - 6 key switches, 1 rotary encoder - 26 accessible IO header pins - USB-C interface, with ESD protection - Antenna
USB
Switch matrix
IOs

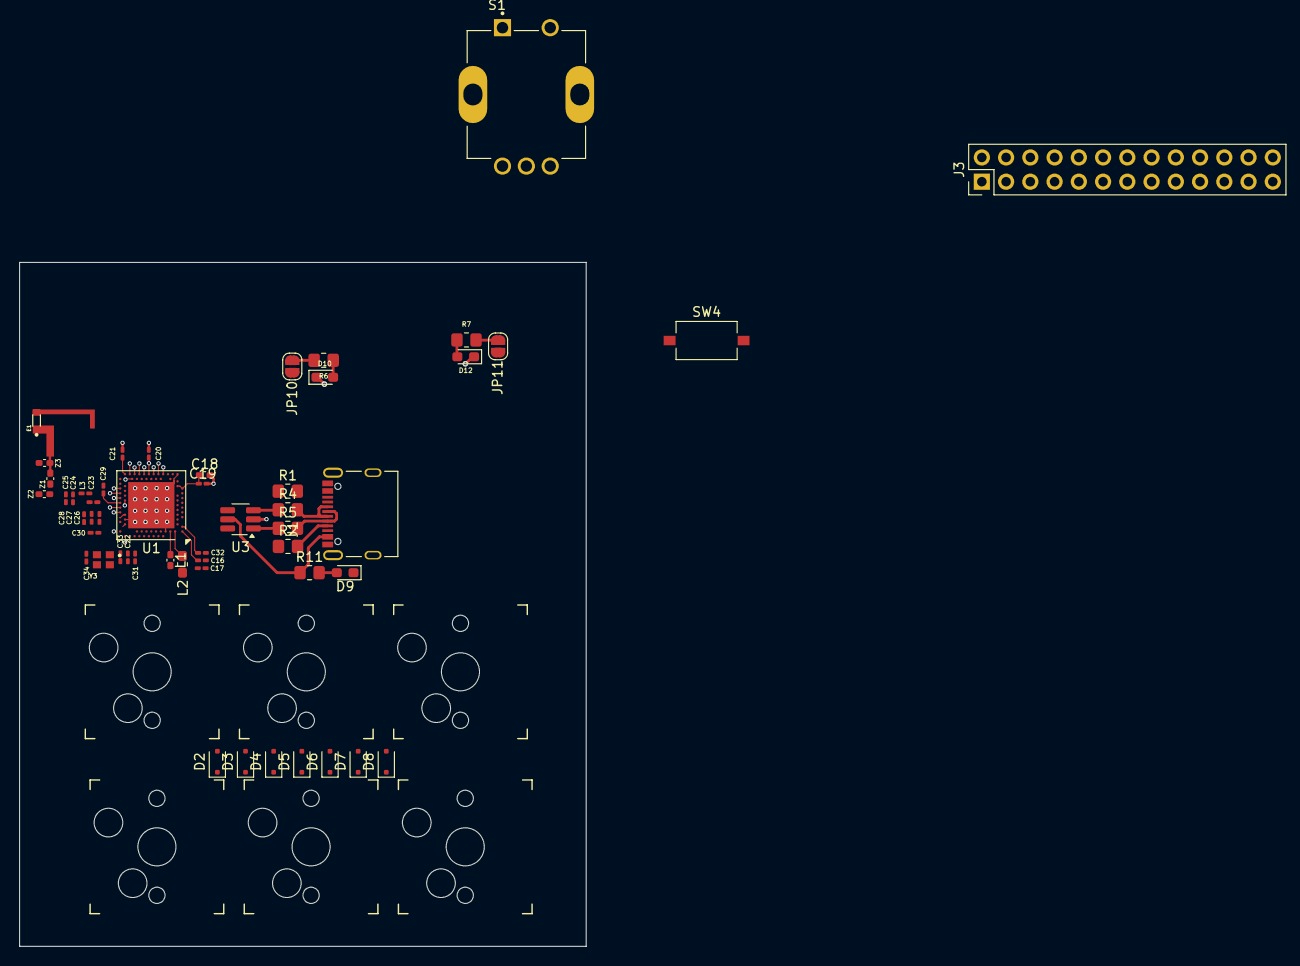
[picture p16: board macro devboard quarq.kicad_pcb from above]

Board: 2 copper layers, 59.4 x 71.6 mm, 58 parts (0 on the bottom side), 42 nets.

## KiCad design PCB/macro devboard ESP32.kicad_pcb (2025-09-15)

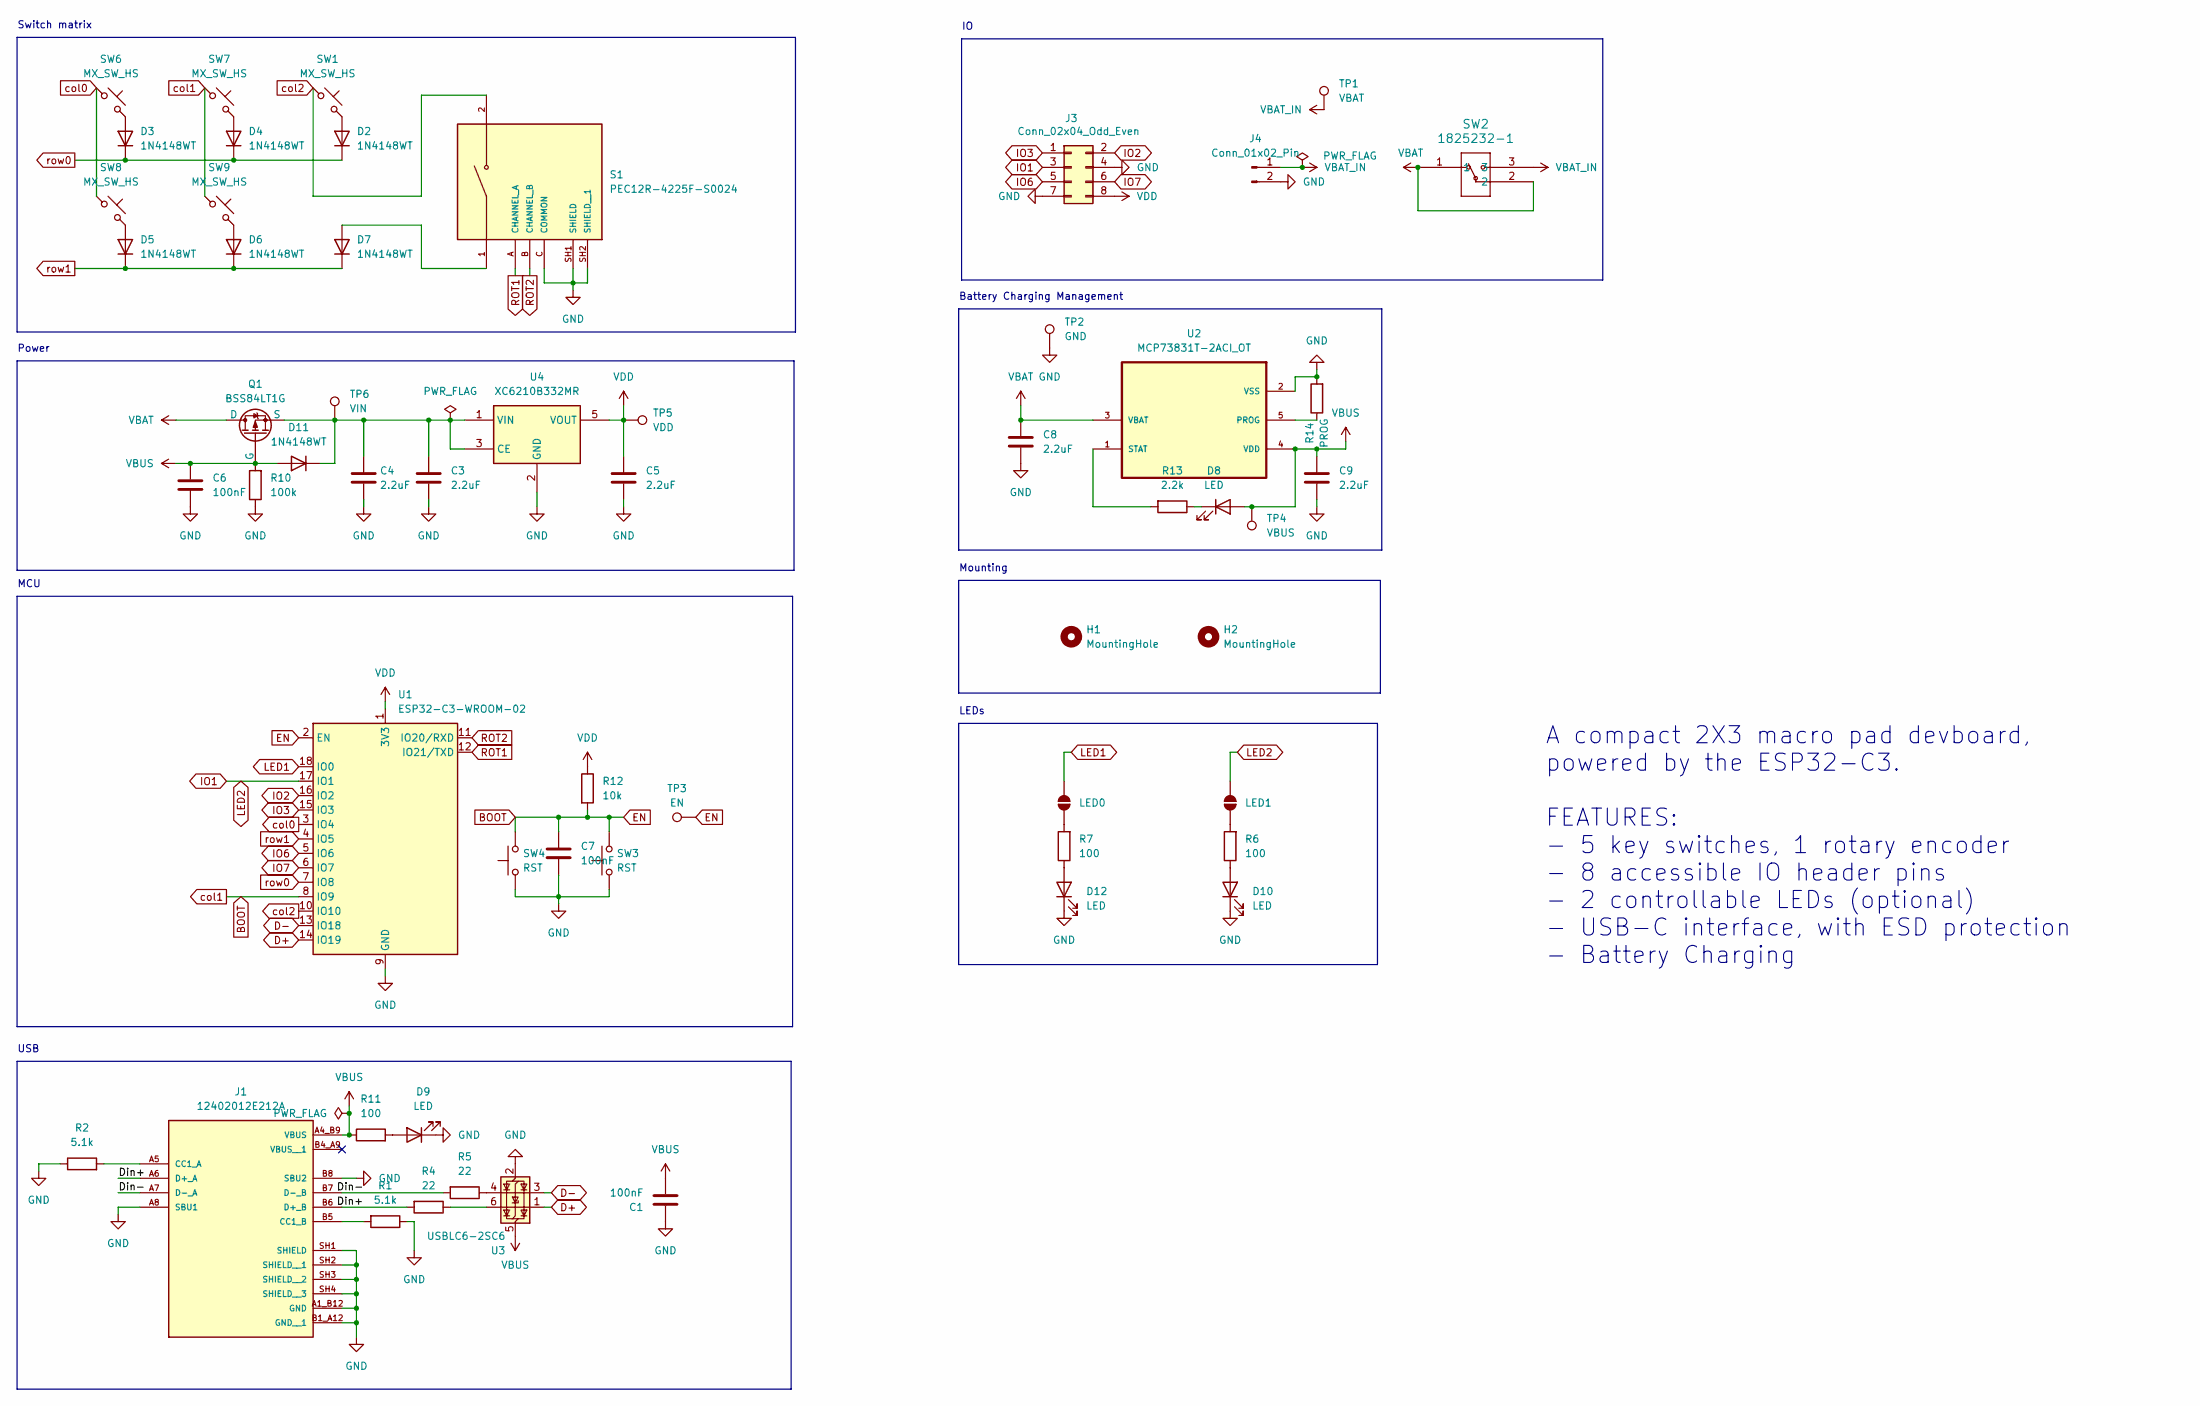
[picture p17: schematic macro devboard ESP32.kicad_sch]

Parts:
C1, C6, C7: 100nF; C_0603_1608Metric_Pad1.08x0.95mm_HandSolder
C3, C4, C5, C8, C9: 2.2uF; C_0603_1608Metric_Pad1.08x0.95mm_HandSolder
D2, D3, D4, D5, D6, D7, D11: 1N4148WT; D_SOD-323F
D8, D9, D10, D12: LED; LED_0805_2012Metric_Pad1.15x1.40mm_HandSolder
H1, H2: MountingHole; MountingHole_2.7mm_M2.5
J1: 12402012E212A; AMPHENOL_12402012E212A; PARTREV 4
J3: Conn_02x04_Odd_Even; PinSocket_2x04_P2.54mm_Vertical
J4: Conn_01x02_Pin; JST_PH_S2B-PH-K_1x02_P2.00mm_Horizontal
LED0, LED1: SolderJumper_2_Open; SolderJumper-2_P1.3mm_Open_RoundedPad1.0x1.5mm
Q1: BSS84LT1G; TSOT-23_HandSoldering
R1, R2: 5.1k; R_0603_1608Metric_Pad0.98x0.95mm_HandSolder
R4, R5: 22; R_0603_1608Metric_Pad0.98x0.95mm_HandSolder
R6, R7, R11: 100; R_0603_1608Metric_Pad0.98x0.95mm_HandSolder
R10: 100k; R_0603_1608Metric_Pad0.98x0.95mm_HandSolder
R12: 10k; R_0603_1608Metric_Pad0.98x0.95mm_HandSolder
R13: 2.2k; R_0603_1608Metric_Pad0.98x0.95mm_HandSolder
R14: PROG; R_0603_1608Metric_Pad0.98x0.95mm_HandSolder
S1: PEC12R-4225F-S0024; XDCR_PEC12R-4225F-S0024; PARTREV 07/21
SW1, SW6, SW7, SW8, SW9: MX_SW_HS; Kailh_socket_MX_optional
SW2: 1825232-1; 1825232-1_TEC
SW3, SW4: RST; SW_Tactile_SPST_NO_Straight_CK_PTS636Sx25SMTRLFS
TP1: VBAT; TestPoint_Pad_D2.0mm
TP2: GND; TestPoint_Pad_D2.0mm
TP3: EN; TestPoint_Pad_D2.0mm
TP4: VBUS; TestPoint_Pad_D2.0mm
TP5: VDD; TestPoint_Pad_D2.0mm
TP6: VIN; TestPoint_Pad_D2.0mm
U1: ESP32-C3-WROOM-02
U2: MCP73831T-2ACI_OT; SOT95P280X145-5N; MPN MCP73831T-2ACI/OT
U3: USBLC6-2SC6; SOT-23-6_Handsoldering
U4: XC6210B332MR; SC-74A-5_1.55x2.9mm_P0.95mm

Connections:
/Din+: J1.A6 (D+_A), J1.B6 (D+_B), R4.2
/Din-: J1.A7 (D-_A), J1.B7 (D-_B), R5.2
BOOT: C7.2, R12.2, SW3.2, SW4.2, SW7.1, SW9.1, TP3.1, U1.2 (EN), U1.8 (IO9); also elsewhere on the board
D+: U1.14 (IO19), U3.1 (I/O1)
D-: U1.13 (IO18), U3.3 (I/O2)
GND: C1.2, C3.1, C4.1, C5.1, C6.1, C7.1, C8.1, C9.2, D9.1 (K), D10.1 (K), D12.1 (K), J1.A1_B12 (GND), J1.A8 (SBU1), J1.B1_A12 (GND__1), J1.B8 (SBU2), J1.SH1 (SHIELD), J1.SH2 (SHIELD__1), J1.SH3 (SHIELD__2), J1.SH4 (SHIELD__3), J3.4, J3.7, J4.2, R1.1, R2.1, R10.1, R14.2, S1.C (COMMON), S1.SH1 (SHIELD), S1.SH2 (SHIELD__1), SW3.1, SW4.1, TP2.1, U1.9 (GND), U1.19 (GND), U2.2 (VSS), U3.2 (GND), U4.2 (GND); also elsewhere on the board
IO1: J3.3, LED1.2 (B), U1.17 (IO1)
IO2: J3.2, U1.16 (IO2)
IO3: J3.1, U1.15 (IO3)
IO6: J3.5, U1.5 (IO6)
IO7: J3.6, U1.6 (IO7)
LED1: LED0.2 (B), U1.18 (IO0)
unnamed: D2.2 (A), SW1.2
unnamed: D3.2 (A), SW6.2
unnamed: D4.2 (A), SW7.2
unnamed: D5.2 (A), SW8.2
unnamed: D6.2 (A), SW9.2
unnamed: D7.2 (A), S1.1
unnamed: D8.1 (K), R13.1
unnamed: D9.2 (A), R11.2
unnamed: D10.2 (A), R6.1
unnamed: C3.2, C4.2, D11.1 (K), Q1.2 (S), TP6.1, U4.1 (VIN), U4.3 (CE)
unnamed: D12.2 (A), R7.1
unnamed: J1.A5 (CC1_A), R2.2
unnamed: J1.B5 (CC1_B), R1.2
unnamed: LED0.1 (A), R7.2
unnamed: LED1.1 (A), R6.2
unnamed: R4.1, U3.6 (I/O1)
unnamed: R5.1, U3.4 (I/O2)
unnamed: R14.1, U2.5 (PROG)
unnamed: R13.2, U2.1 (STAT)
ROT1: S1.A (CHANNEL_A), U1.12 (IO21/TXD)
ROT2: S1.B (CHANNEL_B), U1.11 (IO20/RXD)
VBAT: C8.2, Q1.3 (D), SW2.1, SW2.2, U2.3 (VBAT)
VBAT_IN: J4.1, SW2.3, TP1.1
VBUS: C1.1, C6.2, C9.1, D8.2 (A), D11.2 (A), J1.A4_B9 (VBUS), Q1.1 (G), R10.2, R11.1, TP4.1, U2.4 (VDD), U3.5 (VBUS)
VDD: C5.2, J3.8, R12.1, TP5.1, U1.1 (3V3), U4.5 (VOUT)
col0: SW6.1, SW8.1, U1.3 (IO4)
col2: S1.2, SW1.1, U1.10 (IO10)
row0: D2.1 (K), D3.1 (K), D4.1 (K), U1.7 (IO8)
row1: D5.1 (K), D6.1 (K), D7.1 (K), U1.4 (IO5)

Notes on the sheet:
LEDs
Mounting
A compact 2X3 macro pad devboard, powered by the ESP32-C3. FEATURES: - 5 key switches, 1 rotary encoder - 8 accessible IO header pins - 2 controllable LEDs (optional) - USB-C interface, with ESD protection - Battery Charging
USB
Power
Switch matrix
MCU
Battery Charging Management

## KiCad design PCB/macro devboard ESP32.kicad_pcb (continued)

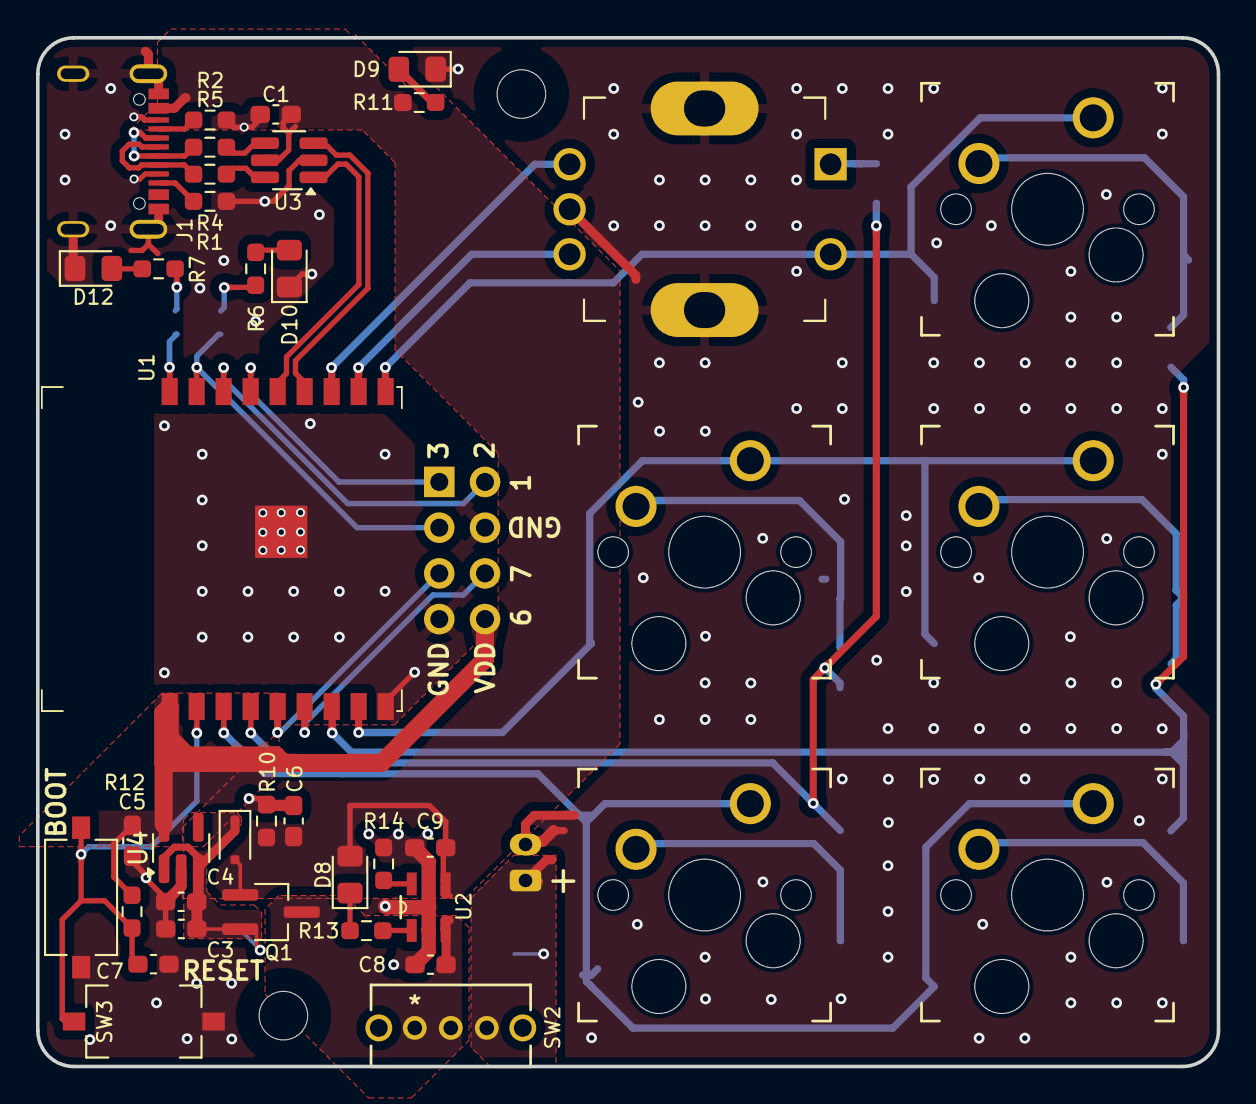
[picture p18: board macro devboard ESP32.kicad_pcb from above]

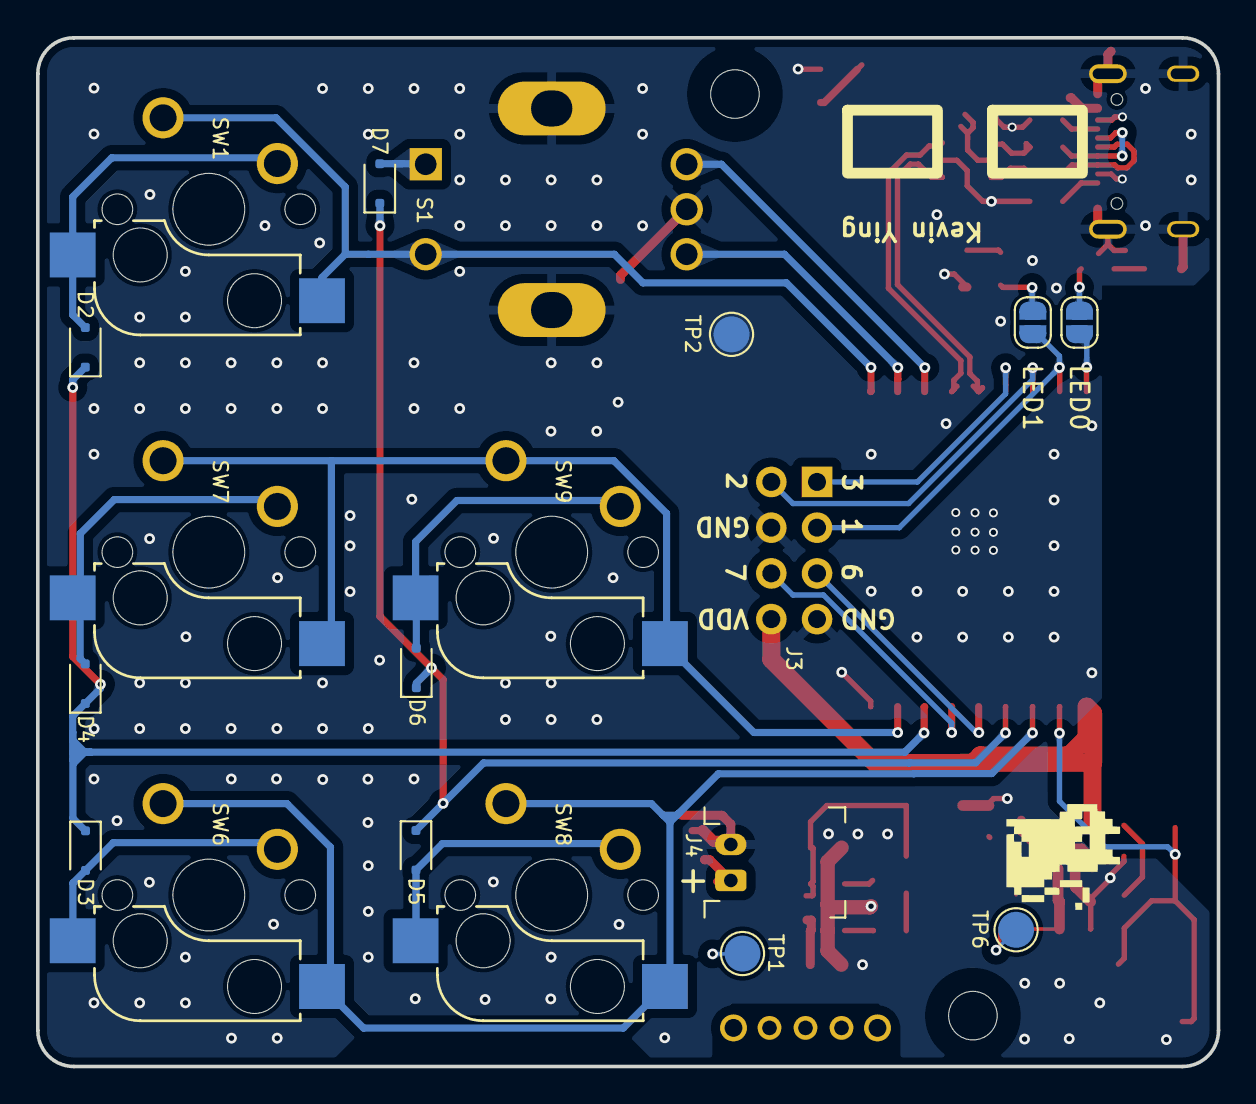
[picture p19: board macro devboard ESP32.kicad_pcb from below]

Board: 4 copper layers, 65.6 x 57.1 mm, 54 parts (13 on the bottom side), 41 nets.

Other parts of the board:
BOOT: RST; SW_Tactile_SPST_NO_Straight_CK_PTS636Sx25SMTRLFS

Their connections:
BOOT: BOOT.2; also elsewhere on the board
GND: BOOT.1; also elsewhere on the board

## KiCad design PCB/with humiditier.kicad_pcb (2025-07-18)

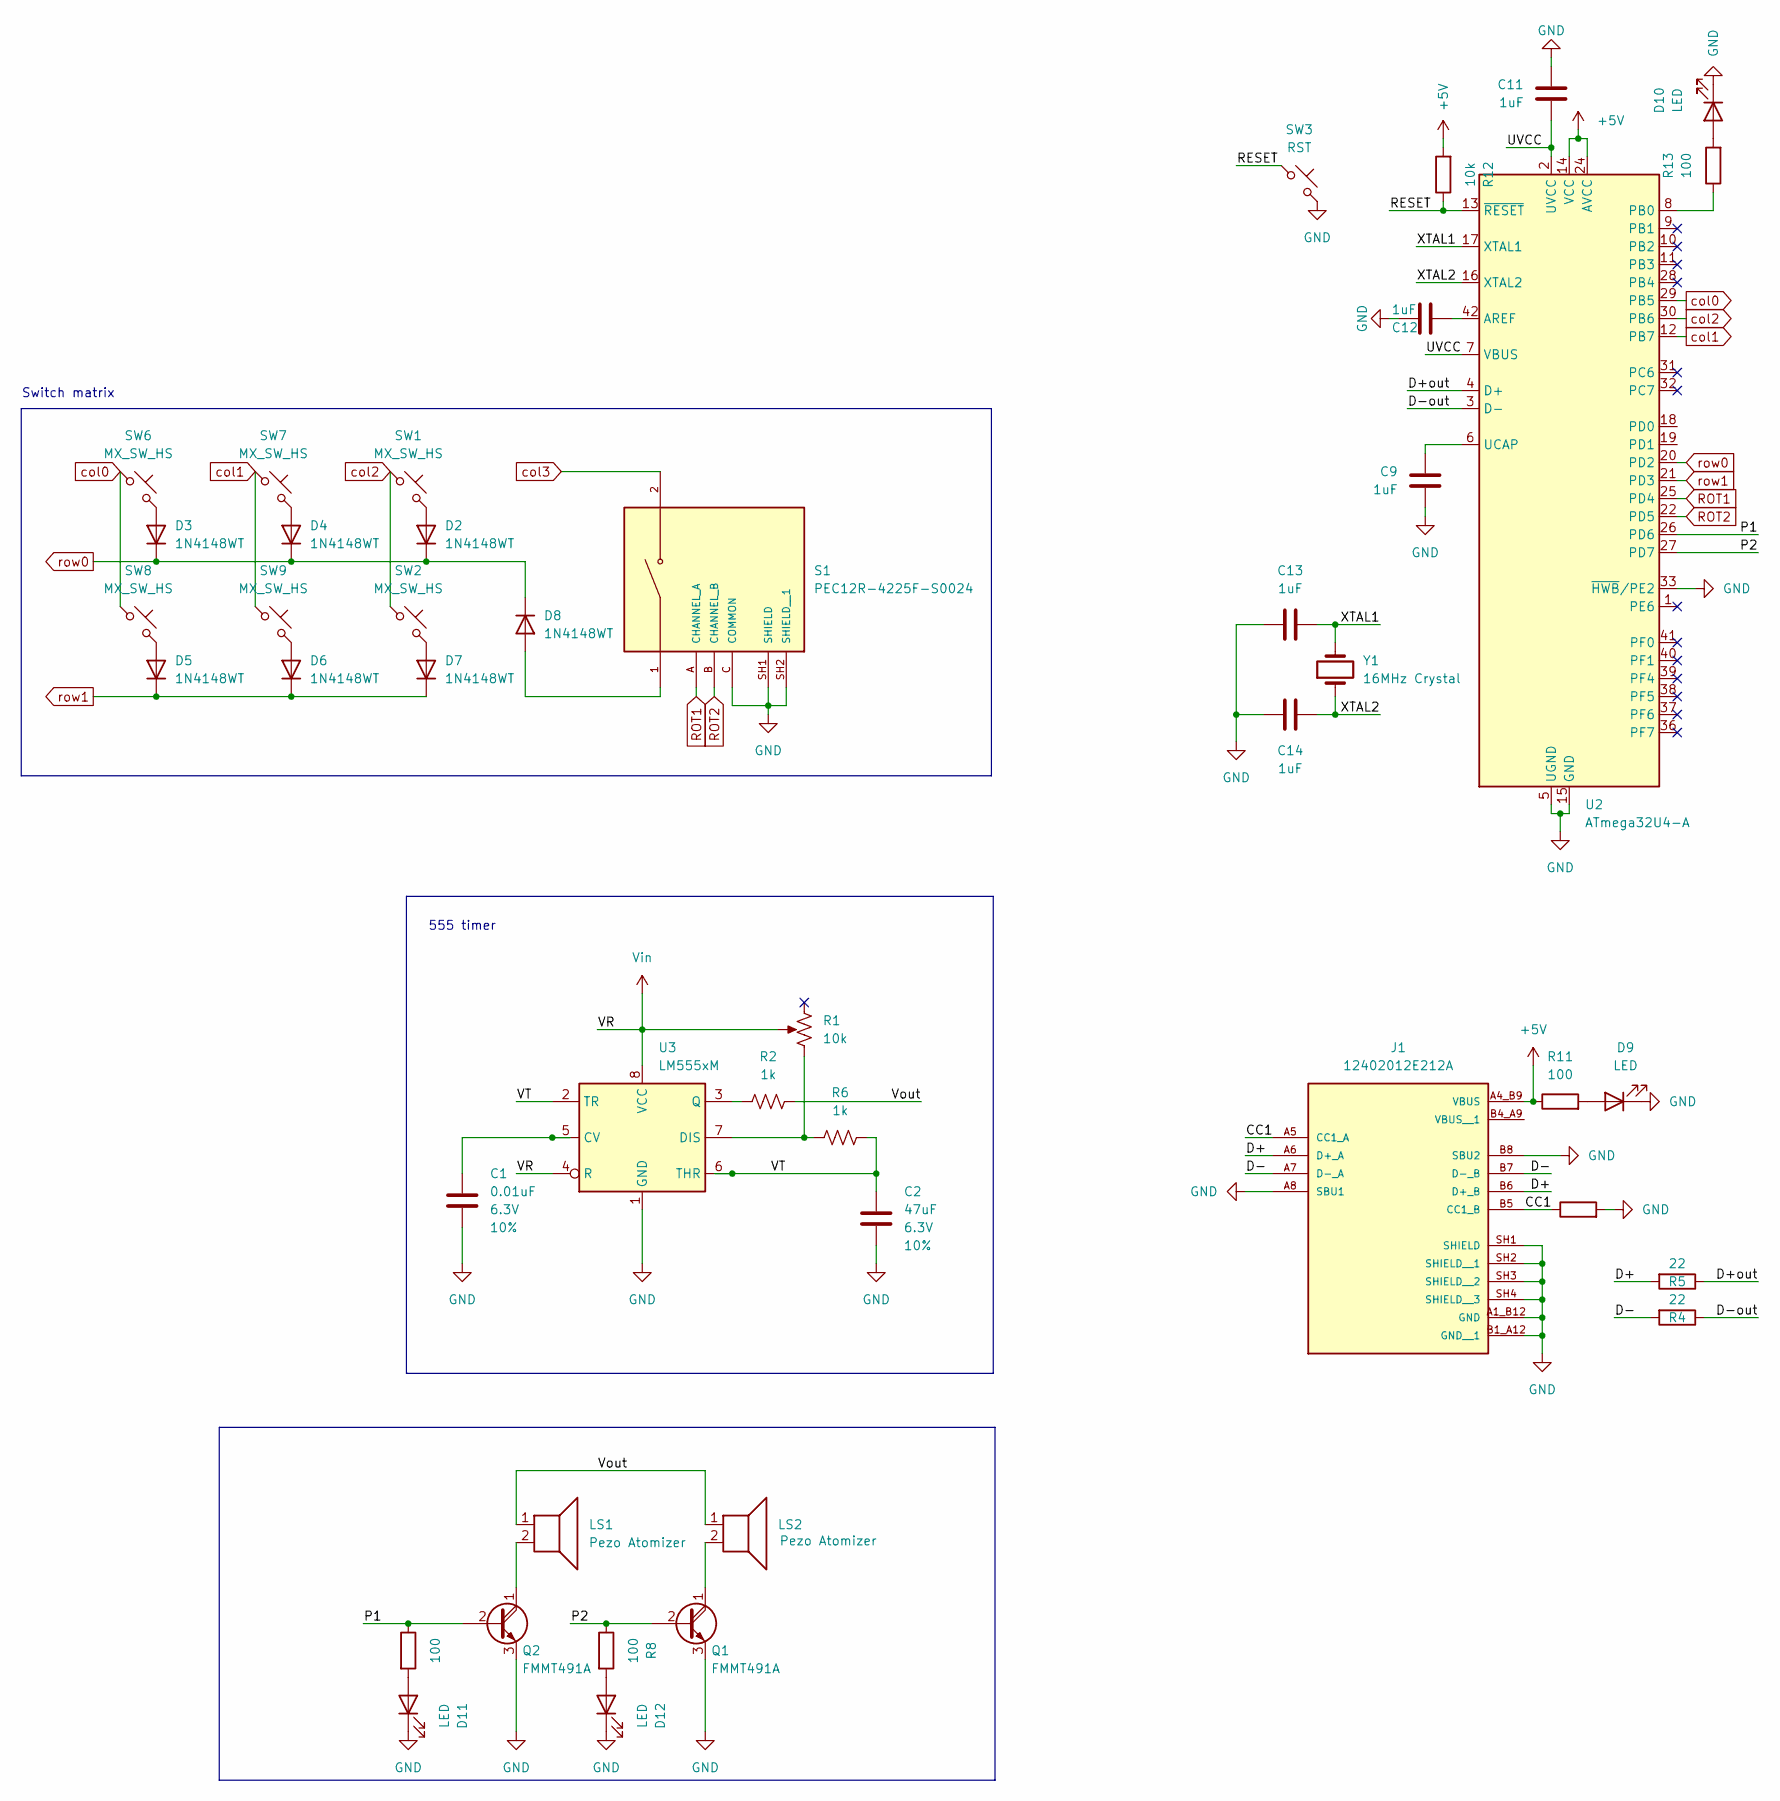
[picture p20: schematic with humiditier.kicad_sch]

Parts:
C1: 0.01uF; C_0805_2012Metric_Pad1.18x1.45mm_HandSolder; Voltage 6.3V; Tolerance 10%
C2: 47uF; C_0805_2012Metric_Pad1.18x1.45mm_HandSolder; Voltage 6.3V; Tolerance 10%
C9, C11, C12, C13, C14: 1uF; C_0805_2012Metric_Pad1.18x1.45mm_HandSolder
D2, D3, D4, D5, D6, D7, D8: 1N4148WT; D_SOD-323F
D9, D10, D11, D12: LED; LED_0603_1608Metric_Pad1.05x0.95mm_HandSolder
J1: 12402012E212A; AMPHENOL_12402012E212A; PARTREV 4
LS1, LS2: Pezo Atomizer; PinHeader_1x02_P2.54mm_Vertical
Q1, Q2: FMMT491A; TO-92_Inline
R1: 10k; TRIM_PV37W103C01B00; Mfg Part# 22AR10K
R2, R6: 1k; C_0805_2012Metric_Pad1.18x1.45mm_HandSolder
R3: 4.7k; R_0805_2012Metric_Pad1.20x1.40mm_HandSolder
R4, R5: 22; R_0805_2012Metric_Pad1.20x1.40mm_HandSolder
R7, R8, R11, R13: 100; R_0805_2012Metric_Pad1.20x1.40mm_HandSolder
R12: 10k; R_0805_2012Metric_Pad1.20x1.40mm_HandSolder
S1: PEC12R-4225F-S0024; XDCR_PEC12R-4225F-S0024; PARTREV 07/21
SW1, SW2, SW6, SW7, SW8, SW9: MX_SW_HS; Kailh_socket_MX
SW3: RST; SW_Tactile_SPST_NO_Straight_CK_PTS636Sx25SMTRLFS
U2: ATmega32U4-A; TQFP-44_10x10mm_P0.8mm
U3: LM555xM; SOIC-8_3.9x4.9mm_P1.27mm
Y1: 16MHz Crystal

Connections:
+5V: J1.A4_B9 (VBUS), R11.1, R12.2, U2.14 (VCC), U2.24 (AVCC), U2.34 (VCC), U2.44 (AVCC)
/CC1: J1.A5 (CC1_A), J1.B5 (CC1_B), R3.1
/D+: J1.A6 (D+_A), J1.B6 (D+_B), R5.2
/D+out: R5.1, U2.4 (D+)
/D-: J1.A7 (D-_A), J1.B7 (D-_B), R4.2
/D-out: R4.1, U2.3 (D-)
/P1: Q2.2 (B), R7.1, U2.26 (PD6)
/P2: Q1.2 (B), R8.1, U2.27 (PD7)
/RESET: R12.1, SW3.1, U2.13 (~RESET)
/UVCC: C11.1, U2.2 (UVCC), U2.7 (VBUS)
/VT: C2.1, R6.2, U3.2 (TR), U3.6 (THR)
/Vout: LS1.1, LS2.1, R2.2
/XTAL1: C13.1, U2.17 (XTAL1), Y1.2
/XTAL2: C14.1, U2.16 (XTAL2), Y1.1
GND: C1.2, C2.2, C9.1, C11.2, C12.2, C13.2, C14.2, D9.1 (K), D10.1 (K), D11.1 (K), D12.1 (K), J1.A1_B12 (GND), J1.A8 (SBU1), J1.B1_A12 (GND__1), J1.B8 (SBU2), J1.SH1 (SHIELD), J1.SH2 (SHIELD__1), J1.SH3 (SHIELD__2), J1.SH4 (SHIELD__3), Q1.3 (E), Q2.3 (E), R3.2, S1.C (COMMON), S1.SH1 (SHIELD), S1.SH2 (SHIELD__1), SW3.2, U2.5 (UGND), U2.15 (GND), U2.23 (GND), U2.33 (~HWB/PE2), U2.35 (GND), U2.43 (GND), U3.1 (GND)
unnamed: D2.2 (A), SW1.2
unnamed: D3.2 (A), SW6.2
unnamed: D4.2 (A), SW7.2
unnamed: D5.2 (A), SW8.2
unnamed: D6.2 (A), SW9.2
unnamed: D7.2 (A), SW2.2
unnamed: D8.2 (A), S1.1
unnamed: D9.2 (A), R11.2
unnamed: D10.2 (A), R13.2
unnamed: D11.2 (A), R7.2
unnamed: D12.2 (A), R8.2
unnamed: LS2.2, Q1.1 (C)
unnamed: LS1.2, Q2.1 (C)
unnamed: C12.1, U2.42 (AREF)
unnamed: R13.1, U2.8 (PB0)
unnamed: C9.2, U2.6 (UCAP)
unnamed: C1.1, U3.5 (CV)
unnamed: R1.1, R6.1, U3.7 (DIS)
unnamed: R2.1, U3.3 (Q)
ROT1: S1.A (CHANNEL_A), U2.25 (PD4)
ROT2: S1.B (CHANNEL_B), U2.22 (PD5)
Vin: R1.2, U3.4 (R), U3.8 (VCC)
col0: SW6.1, SW8.1, U2.29 (PB5)
col1: SW7.1, SW9.1, U2.12 (PB7)
col2: SW1.1, SW2.1, U2.30 (PB6)
col3: S1.2
row0: D2.1 (K), D3.1 (K), D4.1 (K), D8.1 (K), U2.20 (PD2)
row1: D5.1 (K), D6.1 (K), D7.1 (K), U2.21 (PD3)

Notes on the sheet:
Switch matrix
555 timer

Board: 2 copper layers, 43 parts (0 on the bottom side), 42 nets, no tracks yet.

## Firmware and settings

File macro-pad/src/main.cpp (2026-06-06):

#include <Arduino.h>
#include <lvgl.h>

#include "BLE_HID.h"
#include "MacroPad.h"
#include "Rotary_Encoder.h"
#include "Config.h"
#include "Display.h"
#include "TaskSync.h"
#include "ui.h"

// ── Burn-in / sleep state ─────────────────────────────────────────────────────
static unsigned long lastUserActivityMs = 0;

// Two-phase sleep model:
//   isDimmingDown — fade is in progress; input cancels the fade (no swallow)
//   isDisplayDimmed — fade finished, screen fully dark; input wakes + swallows key
static bool          isDimmingDown    = false;
static bool          isDisplayDimmed  = false;
static bool          isFadingToSleep  = false;  // dim→off fade after SLEEP_TIMEOUT_MS
static unsigned long dimmedSinceMs    = 0;       // when we entered the dim state
static bool          swallowNextKey   = false;

// Returns true if the display was sleeping (dim or off) and just woke.
// Key-event callers set swallowNextKey on true; encoder/BLE callers ignore it.
static bool markActivity() {
    lastUserActivityMs = millis();
    if (isDisplayDimmed) {
        isDisplayDimmed = false;
        isFadingToSleep = false;
        setSleepMode(false);
        cancelFade(BRIGHTNESS);  // fade up from wherever brightness currently is
        return true;
    } else if (isDimmingDown) {
        isDimmingDown = false;
        setSleepMode(false);
        cancelFade(BRIGHTNESS);
    }
    return false;
}

BLE_HID ble;

// Rows driven LOW one at a time; cols read with INPUT_PULLUP. Index = r*COLS + c.
//                  col0=GPIO4    col1=GPIO21    col2=GPIO8
//   row0=GPIO1:    [SCREENSHOT]  [SCREEN REC]   [TERMINAL]
//   row1=GPIO5:    [PAUSE]       [NEXT]         [PLAY_PAUSE]
static Key keymap[ROWS * COLS] = {
    // GNOME shortcuts: Print = screenshot UI, Ctrl+Shift+Alt+R = screencast toggle, Ctrl+Alt+T = terminal
    Key::combo(0, HidKey::PRINT_SCREEN),
    Key::combo(Mod::LCTRL | Mod::LSHIFT | Mod::LALT, BLE_HID::charToHidCode('r')),
    Key::combo(Mod::LCTRL | Mod::LALT,               BLE_HID::charToHidCode('t')),
    Key::app(AppKey::PAUSE), Key::app(AppKey::NEXT),  Key::media(MediaKey::PLAY_PAUSE)
};

MacroPad keypad(ble, keymap, ROWS, COLS, ROW_PINS, COL_PINS);
Encoder  encoder(ble, PIN_ENCODER_A, PIN_ENCODER_B);

// ----- Pomodoro state -----
static size_t        currentPhase       = 0;
static int           remainingSeconds   = 0;  // set in setup() from PHASES[currentPhase]
static bool          timerRunning       = false;
static bool          waitingForContinue = false;  // phase ended, waiting for key to advance
static unsigned long lastSecondTick     = 0;
static int           completedSessions  = 0;      // work phases finished; drives break-screen dots

// ----- Tasks -----
static char   tasks[MAX_TASKS][TASK_MAX_LEN] = {
    "GRASP MAP", "TEST", "ORCA HANDOFF", "JOINT MAP*", "TELEOP"
};
static size_t taskCount    = 5;
static size_t taskOffset   = 0;  // first visible task in the queue
static size_t taskSelected = 0;  // highlighted row (0 = top)

static bool timerDirty = true;  // UI needs a timer redraw
static bool tasksDirty = true;  // UI needs a task list redraw

// work phases show the task list; rest phases show a blank screen
static bool isWorkPhase(size_t idx) {
    return strcmp(PHASES[idx].label, "WORK") == 0;
}

// parse newline-separated task names from a BLE payload, lowercase them for the font
static void applyTasks(const char* payload) {
    taskCount = 0;
    const char* p = payload;
    while (*p && taskCount < MAX_TASKS) {
        const char* nl = strchr(p, '\n');
        size_t len = nl ? (size_t)(nl - p) : strlen(p);
        while (len > 0 && (p[len-1] == '\r' || p[len-1] == ' ')) len--;
        if (len > 0) {
            size_t n = len < TASK_MAX_LEN - 1 ? len : TASK_MAX_LEN - 1;
            memcpy(tasks[taskCount], p, n);
            tasks[taskCount][n] = '\0';
            for (char* q = tasks[taskCount]; *q; q++)
                if (*q >= 'a' && *q <= 'z') *q -= 32;
            taskCount++;
        }
        p = nl ? nl + 1 : p + strlen(p);
    }
    taskOffset   = 0;
    taskSelected = 0;
    tasksDirty   = true;
}

// move to next pomodoro phase and reset the countdown
static void advancePhase() {
    if (isWorkPhase(currentPhase)) completedSessions++;  // count the session we're leaving
    currentPhase     = (currentPhase + 1) % PHASE_COUNT;
    remainingSeconds = PHASES[currentPhase].minutes * 60;
    timerDirty = true;
    tasksDirty = true;
}

// count down one second per wall-clock second; stop and wait when time runs out
static void handleTimer() {
    if (!timerRunning) return;
    unsigned long now = millis();
    if (lastSecondTick == 0) { lastSecondTick = now; return; }  // first call: anchor the clock
    if (now - lastSecondTick >= 1000) {
        lastSecondTick += 1000;
        if (remainingSeconds > 0) { remainingSeconds--; timerDirty = true; }
        if (remainingSeconds == 0) {
            timerRunning       = false;
            waitingForContinue = true;
        }
    }
}

// returns true if the key was handled here (prevents MacroPad from forwarding it over BLE)
static bool handleKeyEvent(const Key& key, bool pressed) {
    if (key.type != KeyType::APP) return false;

    // If this key woke the display, arm the swallow so the action doesn't also fire.
    // Encoder wakes don't go through here, so they never accidentally arm the swallow.
    if (markActivity()) swallowNextKey = true;

    if (swallowNextKey) {
        if (!pressed) swallowNextKey = false;  // clear on release so next press is normal
        return true;
    }

    if (key._app == AppKey::PAUSE && pressed) {
        if (waitingForContinue) {
            bool wasRest       = !isWorkPhase(currentPhase);
            waitingForContinue = false;
            advancePhase();
            if (wasRest && taskCount > 1 && taskOffset < taskCount - 1) {
                taskOffset++;    // after a rest, surface the next task automatically
                taskSelected = 0;
            }
            lastSecondTick = 0;
            timerRunning   = true;
        } else {
            timerRunning = !timerRunning;
            if (timerRunning) lastSecondTick = 0;  // re-anchor clock on unpause
            timerDirty   = true;
        }
        return true;
    }

    if (key._app == AppKey::NEXT && pressed) {
        if (taskCount > 0 && taskOffset < taskCount - 1) {
            taskOffset++;
            taskSelected = 0;
            tasksDirty   = true;
        }
        return true;
    }

    return false;
}

void setup() {
    remainingSeconds = PHASES[currentPhase].minutes * 60;  // derive from whichever phase is set
    Serial.begin(115200);
    ble.begin("ESP32 MacroPad");
    setupTaskService(ble);
    ble.startAdvertising();  // last: NimBLE freezes the GATT table once the server starts
    keypad.begin();
    keypad.setKeyHandler(handleKeyEvent);
    encoder.begin();
    setupDisplay();
    createUI();
    updateTimer(remainingSeconds, PHASES[currentPhase].label, timerRunning, waitingForContinue, completedSessions);
    updateTaskQueue(tasks, taskCount, taskOffset, taskSelected);
}

void loop() {
    ble.tick();  // flush any deferred media-key release from the previous iteration
    keypad.handleKeypad();

    encoder.handle();
    int delta = encoder.consumeDelta();
    if (delta != 0) markActivity();  // encoder turn = user input
    while (delta < 0) { ble.sendMediaKey(MediaKey::VOL_UP);   delta++; }
    while (delta > 0) { ble.sendMediaKey(MediaKey::VOL_DOWN); delta--; }

    handleTimer();

    static char payload[MAX_TASKS * TASK_MAX_LEN + 32];
    if (getNextTaskPayload(payload, sizeof(payload))) { applyTasks(payload); markActivity(); }

    if (timerDirty) {
        updateTimer(remainingSeconds, PHASES[currentPhase].label, timerRunning, waitingForContinue, completedSessions);
        timerDirty = false;
    }
    if (tasksDirty) {
        updateTaskQueue(tasks, taskCount, taskOffset, taskSelected);
        tasksDirty = false;
    }

    // feed LVGL the elapsed time so its animations and timers run correctly
    static unsigned long lastTick  = 0;
    static unsigned long lastShift = 0;
    unsigned long now = millis();
    if (lastTick  == 0) lastTick  = now;
    if (lastShift == 0) lastShift = now;

    // Start the fade-down once after DIM_TIMEOUT_MS of inactivity.
    if (!isDisplayDimmed && !isDimmingDown && (now - lastUserActivityMs) > DIM_TIMEOUT_MS) {
        isDimmingDown = true;
        setSleepMode(true);                           // switch to minimal centered UI
        startFade(BRIGHTNESS, DIM_BRIGHTNESS, 2000);  // 2 s fade-down
    }

    // When the fade-down completes, enter the dim state and start the sleep clock.
    bool stillFading = tickFade();
    if (isDimmingDown && !stillFading) {
        isDimmingDown   = false;
        isDisplayDimmed = true;
        dimmedSinceMs   = now;
    }

    // After SLEEP_TIMEOUT_MS in the dim state, fade to fully off.
    // isFadingToSleep prevents re-triggering once the fade has started.
    if (isDisplayDimmed && !isFadingToSleep && (now - dimmedSinceMs) > SLEEP_TIMEOUT_MS) {
        isFadingToSleep = true;
        startFade(DIM_BRIGHTNESS, 0, 2000);
    }

    // Pixel shift: nudge the label every SHIFT_INTERVAL_MS to distribute stress.
    if (now - lastShift >= SHIFT_INTERVAL_MS) {
        lastShift = now;
        shiftPixels();
    }

    lv_tick_inc(now - lastTick);
    lastTick = now;
    lv_timer_handler();
    delay(5);
}

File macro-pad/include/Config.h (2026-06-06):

#ifndef MACROPAD_CONFIG_H
#define MACROPAD_CONFIG_H

#include <Arduino.h>
#include <string.h>

// Keypad matrix (2R × 3C)
static constexpr uint8_t ROWS = 2;
static constexpr uint8_t COLS = 3;
// Defined once in Config.cpp — avoids duplicate copies in every translation unit.
extern const uint8_t ROW_PINS[ROWS];  // {1, 5}
extern const uint8_t COL_PINS[COLS];  // {4, 21, 8}

// Encoder
static constexpr uint8_t PIN_ENCODER_A = 3;
static constexpr uint8_t PIN_ENCODER_B = 10;

// Display — ST7789 240×280, 4-wire SPI
static constexpr int PIN_TFT_SCK  = 7;
static constexpr int PIN_TFT_MOSI = 6;
static constexpr int PIN_TFT_MISO = -1;
static constexpr int PIN_TFT_DC   = 2;
static constexpr int PIN_TFT_CS   = 0;
static constexpr int PIN_TFT_RST  = 9;
static constexpr int PIN_TFT_BL   = 20;
static constexpr int     BRIGHTNESS        = 150;    // 0-255 PWM for backlight; ignored if PIN_TFT_BL < 0
static constexpr uint8_t DIM_BRIGHTNESS    = 50;      // PWM when dimmed — low but not off
static constexpr uint32_t DIM_TIMEOUT_MS   = 20000;  // ms idle before dimming
static constexpr uint32_t SLEEP_TIMEOUT_MS = 300000; // ms in dim state before full off (5 min)
static constexpr uint32_t SHIFT_INTERVAL_MS = 12000; // ms between pixel-shift steps (anti-burn)

// Logical (post-rotation) dimensions; physical panel is portrait 240×280.
static constexpr int TFT_WIDTH    = 280;
static constexpr int TFT_HEIGHT   = 240;
static constexpr int TFT_ROTATION = 1;
static constexpr int TFT_OFFSET_X = 0;
static constexpr int TFT_OFFSET_Y = 20;

// UI grid padding
static constexpr int UI_PADDING     = 20;
static constexpr int UI_PADDING_TOP = 30;

// Pomodoro
struct Phase { const char* label; uint16_t minutes; bool bigDot; };

// PHASE_COUNT must match the array in Config.cpp.
static constexpr size_t PHASE_COUNT      = 8;
static constexpr size_t LONG_BREAK_PHASE = PHASE_COUNT - 1;
extern const Phase PHASES[PHASE_COUNT];

// Tasks
static constexpr size_t MAX_TASKS    = 12;
static constexpr size_t TASK_MAX_LEN = 32;  // max chars per stored task name (incl. null)

#endif

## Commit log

2025-07-02 a bunch of work
    [DM-OLED096-636.step, PEC12R-4225F-S0024.step, Untitled.kicad_pcb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]
2025-08-26 used keypad, which doesn't work
    [OS102011MA1QN1.stp, c-1825232-1-b-3d.stp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]
2025-09-08 Revert "key register working!"
    This reverts commit 267d64cb3103f37808471bd2d2e793a2cff04a2e.
    [main.cpp]
2025-09-13 keystrokes + encoder working
2025-09-14 encoder good
2025-09-15 fixed GPIOs for SPI
    [macro devboard ESP32.kicad_pcb, macro devboard ESP32.kicad_sch]
2026-05-20 updated pin assignment
2026-06-04 buttons work again mostly
